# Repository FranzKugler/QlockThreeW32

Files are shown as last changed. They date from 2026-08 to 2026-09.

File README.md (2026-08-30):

# QlockThreeW32

ESP32 firmware for a **word clock** — a grid of letters, backlit so that the
current time reads as a sentence. The display changes every five minutes; four
corner LEDs fill in the minutes in between.

```
ES IST FÜNF NACH ZWEI          IT IS FIVE PAST TWO
```

Ten languages and dialects, a configuration web interface served by the clock
itself, and firmware updates through the browser. No cloud, no app, no account
— everything the clock needs it carries, and it works on a network with no
internet access at all.

---

## What it does

- **Ten languages**: German (standard, Swabian, Bavarian, Saxon), Swiss German,
  English, French, Italian, Dutch, Spanish. Each has its own irregular grammar
  — French and Italian agree the hour, the German dialects differ on
  *viertel* / *dreiviertel*.
- **Configuration in the browser**, served from the clock. The interface
  switches its own language along with the clock's.
- **Colour** as hue, saturation and brightness, beside a live preview of the
  real face — the lit letters are read back out of the clock's own frame
  buffer, not guessed at in the browser.
- **Automatic brightness** from an ambient light sensor, on a curve the clock
  learns from the way you use the slider — and, on a calibrated clock,
  **colour-aware**: the same setting emits far less light in deep blue than
  in green, and the automatic knows it. There is no "remember this" button.
- **Time from NTP**, with a region/place picker over both daylight-saving
  changeover rules, which stay editable by hand underneath.
- **Firmware and interface updates** from the browser, or automatically from a
  release channel.
- **Expert mode** — a password in front of the update, debug and storage tabs.
- A few debug displays: seconds counter, LED test pattern.

## Hardware

| | |
|---|---|
| Controller | Seeed XIAO ESP32-S3 **Plus** (16 MB flash) |
| LEDs | 114 × WS2812B on one strip, data on GPIO 4 |
| Layout | 11 × 10 letters = 110, plus 4 corner LEDs |
| Light sensor | ams **TSL2591** (0x29) or Vishay **VEML7700** (0x10) on I²C, SDA/SCL default to GPIO 5/6 — optional |

The strip starts at the **bottom right** letter, meanders left, then up one row
and back to the right, and ends at the **top right**. The four corner LEDs
follow it, in the order bottom right, top right, top left, bottom left.

```
index 0    bottom right   (the R of the German panel)
index 109  top right      (the F)
110 … 113  the corners
```

> `LedDriverWS2812FastLED::physicalFor(row, col)` is the only place that
> computes this, and the `/lab` interface can check any claim about it against
> the strip in seconds. Which frame buffer *row* is which corner is a separate
> question and lives at `Renderer::setCorners` — the path there goes through
> two remappings that partly cancel, and it was settled by watching a clock
> rather than by reading code.

**Either light sensor works, and the choice is made at run time** — the firmware
tries each in turn at boot and keeps the first that answers, so one build
serves every clock and a chip swapped on the bench needs no rebuild. The
TSL2591 is asked first: the two do not share an address, so a clock carrying
both answers twice, and the more sensitive one is the one to keep. With no
sensor fitted, the automatic hides itself rather than offering a switch that
does nothing.

The board and the case are in [`hardware/`](hardware/) — a KiCad project and an
OpenSCAD model. The letter mask is **not** drawn by hand: `scripts/panels.py`
reads the ten rows out of the firmware's own language files and writes
`panels.scad`, so the sheet that gets milled and the words the clock lights
cannot drift apart.

Earlier revisions supported other boards and LED drivers; the project has since
been consolidated onto this single target.

## Building

Two halves are built separately: the firmware, and the web interface that is
flashed into the clock's filesystem.

```sh
# web interface -> data/
npm install
npm run build

# firmware
pio run                  # build
pio run -t upload        # flash the firmware
pio run -t uploadfs      # flash data/ as the filesystem image
```

Both have to be flashed once over USB. After that, updates can go through the
browser.

> The board definition in PlatformIO describes the 8 MB XIAO ESP32-S3. This is
> the Plus with 16 MB, so [`platformio.ini`](platformio.ini) overrides the
> flash size and points at [`partitions.csv`](partitions.csv): two 6.5 MB OTA
> slots and a 3.5 MB filesystem.

### Credentials

Copy [`src/Secrets.example.h`](src/Secrets.example.h) to `src/Secrets.h` and
put in your own values — it is not in version control. The build works without
it, it just leaves network flashing via espota unprotected and says so with a
compiler warning.

## First start

With no WiFi configured the clock opens an access point called
**QlockThreeW32**. Connect to it and a captive portal asks for the network.
Afterwards the clock is reachable at **http://qlockthreew32.local** or by its
address in the network.

The clock can be renamed in the WLAN tab, which changes all six places the name
appears — mDNS, the DHCP name the router lists, the setup access point, the
espota target, the RemoteDebug host and the heading of the interface. It
restarts to do it, and says so.

Four tabs are open to anyone on the network:

| Tab | |
|---|---|
| Display | operating mode, language, corner LED direction and colour |
| Colour | hue, saturation, brightness, the automatic, and a preview of the face |
| Time zone | NTP server, a region/place picker, and both changeover rules |
| WLAN | status, scan, switching networks, renaming the clock |

Switching networks is deliberately careful: the clock tries the new
credentials, and if they do not come up within twenty seconds it returns to the
previous network by itself, so a typo cannot lock you out.

## Expert mode

Three more tabs — **Update**, **Debug** and **Storage** — are behind a
password, because flashing the clock, reading its log and rummaging through its
filesystem are not things every guest on the network should be able to do.

**The way in is the address bar: `http://<clock>/#expert`.** There is no chip
in the tab row, on purpose; a visible one would only invite guessing.

- A clock that has never been given a password takes the first one offered, and
  keeps it. Until then it is exactly as open as every clock was before this
  existed.
- It is a **mode, not a login**: one flag in NVS, so the password crosses the
  wire once instead of on every poll of the log. While unlocked, nothing is
  protected — hence the visible "lock again" button.
- **The way back from a forgotten password is the plug.** The enrolment can be
  cleared within five minutes of a *power-on* reset, which a restart from the
  clock's own update tab does not count as. Anyone who can pull the plug can
  read the flash over USB anyway, so this admits what is already true rather
  than pretending otherwise.
- Five wrong answers stop the endpoint for five minutes.

What it is worth: it keeps out someone who joins the network and goes looking.
It does not keep out someone watching the traffic — there is no TLS on the
clock — and it does not keep out anyone holding it.

Once unlocked:

| Tab | |
|---|---|
| Update | installed versions, browser upload, release channel and automatic installs |
| Debug | uptime, reset reason, heap, and the clock's last 200 log lines |
| Storage | a file explorer over LittleFS, and over NVS drawn as a tree |

### The lab interface

`/lab/*` hands a script direct control of every pixel and of the light sensor —
raw colours, no gamma, no smoothing, and a whole measurement series in one
request. [`scripts/lab.py`](scripts/lab.py) is the client:

```sh
python scripts/lab.py <address> find   # which cell is the light sensor in
python scripts/lab.py <address> ir     # does the infrared channel see the room
python scripts/lab.py <address> map    # coupling from every cell to the sensor
```

It is there because a word clock whose sensor can see its own face cannot
regulate on it, and how badly is a question of geometry that differs from clock
to clock. On the first clock it ran on it found the sensor in four minutes,
behind an unused filler letter three rows from the bottom.

Behind expert mode, and it never touches a setting: the mode it uses cannot be
stored, cannot be picked in the display tab, and ends with a restart.

Two more screens have no chip either. `#luminance` draws what the automatic
brightness has learned — deliberately *outside* expert mode, since there is no
secret in a brightness curve. `#expert` is the one above.

## Automatic brightness

Switch it on in the colour tab and the display follows the room. The curve is a
straight line in **log light**, because perception is roughly logarithmic and
the range to cover spans decades:

```
brightness = slope × log10(lux) + offset      held between 20 % and 100 %
```

**There is no "remember this" button, and that is the design.** Moving the
slider is the only signal anyone ever gives about whether the automatic got it
right, so the nudge *is* the calibration:

1. Move the brightness slider while the automatic is on. The automatic steps
   aside at once — nobody wants the clock arguing back mid-drag.
2. Ten seconds after the last move, the clock keeps the pair *(light now,
   brightness asked for)* and fits a new line through everything it has kept.

The switch keeps saying "automatic" throughout, because it still is: it is
being taught, not turned off. The timer is in the firmware, so closing the tab
mid-adjustment does not lose the point.

Ten points are kept, in NVS. A new one **replaces a near neighbour** rather
than joining the queue, or ten corrections made in one evening would push the
one daylight point out and collapse the line onto a single lighting condition.
If the points sit too close together to say anything about steepness, only the
level is re-fitted and the slope stands. A slope that would make a darker room
brighter is refused outright.

The reset button in the colour tab throws it all away and restores a cautious
default line.

### Colour-aware, on a calibrated clock

That single line is the fallback. A clock shipped with a measured optical
profile knows that a percentage is not an amount of light — the same setting
emits far less in deep blue than in the green this clock normally shows — and
regulates on a small model of the diffuser and LEDs instead: one line shared
by every colour, plus how each hue departs from it. Nudging the slider still
teaches it, now per colour, and a taught correction only overrides the factory
measurement where it actually disagrees with it — elsewhere the factory
number keeps speaking for itself, which is why a handful of evening
corrections in one colour do not retune the whole curve.

`#luminance` — reachable without unlocking expert mode, since there is no
secret in a brightness curve — draws the model as an interactive 3D surface:
hue running round, ambient light out from the centre (logarithmically,
brighter towards the middle), brightness as the height, with every taught
correction marked on it. A collapsible "fit parameters" section beside it has
the numbers themselves, for anyone curious.

## The two stores

The clock keeps things in two places, and the difference decides what survives
an update:

- **LittleFS**, 3.5 MB — the web interface, the timezone list, the icons. A
  filesystem update **overwrites it whole**.
- **NVS** — the settings, the expert password, the brightness curve. An update
  leaves it **untouched**, which is exactly why they live there.

The **Storage** tab shows both. NVS is not a filesystem and is drawn as one
anyway: namespaces as folders, keys as files, `.json` or `.bin` depending on
what the value turns out to be. Files can be downloaded, uploaded and edited in
place, JSON laid out on the way in and written back compact. Right-click, or
press and hold on a touch screen, for the menu.

Two things it will not do. The expert password hash is listed but never handed
out — it is the one secret whose leak would outlive the unlock that leaked it.
And deleting is not recursive, because a file explorer that empties a tree on
one click is how the web interface gets deleted by someone who meant to tidy
up.

> Clearing NVS resets the clock to defaults. Reflashing the filesystem no
> longer does.

## Flashing a blank chip

**[franzkugler.github.io/QlockThreeW32](https://franzkugler.github.io/QlockThreeW32/)**
flashes a factory-fresh Seeed XIAO ESP32-S3 Plus straight from Chrome, Edge or
Opera — no PlatformIO, no Python, nothing to install. It writes the whole
chip (bootloader, partition table, firmware and the configuration interface)
from whatever the latest stable release is, using
[ESP Web Tools](https://esphome.github.io/esp-web-tools/) over the Web Serial
API. Once a clock is running this firmware, updates go through its own
**Update** tab instead — see the next section.

The page is [`docs/`](docs/) in this repository, published as a GitHub Pages
site by [the release workflow](.github/workflows/release.yml) on every stable
release; see [`CLAUDE.md`](CLAUDE.md) for why it cannot simply point at the
release's own download URLs.

## Updating over the air

There are two images, and they are independent: `firmware.bin` (the program)
and `littlefs.bin` (the web interface). Changing the interface and only
flashing the firmware leaves the old interface in place.

Ready-built images come from
[the releases page](https://github.com/FranzKugler/QlockThreeW32/releases), in
two channels:

- **stable** — tagged versions, built from a `v*` tag.
- **edge** — a rolling build of the latest commit on `main`, replaced on every
  push. Untested by definition.

The clock can poll its channel by itself and install what it finds. Automatic
installs are off by default and only ever run between 02:00 and 05:00 local, so
the face never goes dark in the evening.

Locally the images are produced by `pio run` and `pio run -t buildfs` in
`.pio/build/seeed_xiao_esp32s3/`.

Upload either image in the **Update** tab — the clock recognises which is which
from the image itself (ESP32 program images start with the magic byte `0xE9`)
and picks the right partition.

The checksum is verified before the boot partition is switched, so an
interrupted upload does no harm: the clock simply keeps running the version it
has. There is no automatic rollback for an image that flashes correctly but
then crashes — that case needs a USB cable.

**The update endpoints are behind expert mode**, along with the log and the
storage tab. They were open by design while none of them existed as a web page.

## Layout of the repository

```
src/            firmware (PlatformIO / Arduino-ESP32)
  Renderer.*      hour/minute -> which words light up, no hardware involved
  languages/      one file per language: its letters, its words, its grammar
  LedDriver*      WS2812B output, colour and brightness
  LightSensor.*   TSL2591 / VEML7700 behind one interface, sampled on core 0
  Luminance.*     the brightness curve, and how it is learned
  FactoryProfile.*    the colour-aware model, as pure arithmetic
  FactoryLuminance.*  loads and validates the measured profile from LittleFS
  ResidualStore.*     what an owner has taught it, refit online against the profile
  Settings.*      persistence in NVS
  WebRoutes.*     the HTTP handlers; OtaUpdate, FileRoutes, NvsRoutes beside it
web/            configuration interface (Svelte 5 + Vite), built into data/
hardware/       KiCad project, and the OpenSCAD case and letter mask
scripts/        generators: the letter mask, the timezone list, the app icons
server.js       mock of the clock's REST API, for developing the UI without hardware
```

Everything in `scripts/` writes files that are **committed**, so neither a
build nor a 3D print needs Python. Edit the generator, never its output.

For UI work, run the mock and the dev server side by side — the interface then
behaves as it does on the device, on a desktop browser:

```sh
npm run mock     # REST API on :8080
npm run dev      # Vite with hot reload on :5173
```

[`CLAUDE.md`](CLAUDE.md) goes into the architecture in more detail.

## Origins

This is a long-running hobby project, and not the beginning of the story. It
descends from **Qlockthree** by *Christian Aschoff* — firmware for a
self-built QLOCKTWO-style clock, written for the Arduino/ATmega328 from
November 2011 onwards and maintained through version 3.4.9. Much of the
rendering code here is still his, as the file headers record.

- Project and downloads: <http://www.christians-bastel-laden.de/DOWNLOADS/index.html>
- Shop and build instructions: <http://www.christians-bastel-laden.de/>

The upstream firmware is not on GitHub itself; it is published as ZIP archives
on that page. Several people have mirrored and continued it, among them
[bracci/Qlockthree](https://github.com/bracci/Qlockthree),
[schwabe/qlockthree](https://github.com/schwabe/qlockthree) and
[cactus-online/Qlockthree](https://github.com/cactus-online/Qlockthree).
[bracci/QlockWiFive](https://github.com/bracci/QlockWiFive) and
[ch570512/Qlockwork](https://github.com/ch570512/Qlockwork) are separate ESP
firmwares for the same hardware idea.

Beyond that, the Swiss German variant goes back to *Thomas Schuler* and the
Dutch one to *Rudolf Klimesch*.

This repository takes that lineage to an ESP32-S3, and adds the web interface,
the WiFi handling and the over-the-air updates.

## License

**CC BY-NC-SA 3.0** — Attribution, NonCommercial, ShareAlike. See
[`LICENSE`](LICENSE).

This is inherited, not chosen: Christian Aschoff puts the original firmware
under CC BY-NC-SA 3.0, and the ShareAlike term carries over to anything built
on it. In short — keep the attributions, do not use it commercially, and pass
derivatives on under the same terms.

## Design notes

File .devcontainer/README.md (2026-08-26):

# QlockThreeW32 development container

The container pins the development tools used by this repository:

- Debian 12 / Node.js 22
- Python 3.11
- PlatformIO Core 6.1.19
- Claude Code 2.1.246
- uv 0.12.5

The repository is bind-mounted at `/workspace`. PlatformIO, npm, and Claude
state use separate named volumes, so package downloads and authentication
survive container recreation. The container has no Docker socket, no devices,
no added capabilities, is not privileged, and runs as UID/GID 1001.

## Commands

From the repository root:

```bash
./scripts/dev-container.sh up       # build and start
./scripts/dev-container.sh shell    # interactive shell
./scripts/dev-container.sh build    # npm + firmware + LittleFS
./scripts/dev-container.sh claude   # interactive Claude Code
./scripts/dev-container.sh down     # stop; keep caches
```

Claude authentication is intentionally separate from the host credential
store. Run `./scripts/dev-container.sh claude`, complete `claude auth login`
once, and the login is retained in the `claude-state` volume.

The Vite UI is bound to host loopback port 5173. The mock API remains on port
8080 inside the container but is published as `127.0.0.1:18080`, because port
8080 on this server is already used by another service.

## VS Code

Open the repository and choose **Dev Containers: Reopen in Container**. The
configuration is in `devcontainer.json` and installs the PlatformIO and Svelte
extensions.

## ESP32 USB access

No USB device is exposed by default. Builds and filesystem image creation work
without it. Flashing will be added as a deliberate, device-specific Compose
override after the ESP32 is physically attached and its stable `/dev/serial/by-id/`
path and group ownership are known. Do not use `privileged: true`.

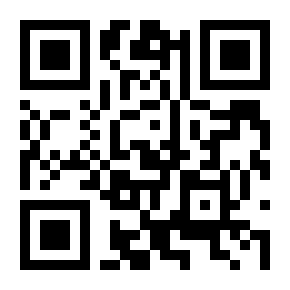
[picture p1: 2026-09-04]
docs/qr-clock.png

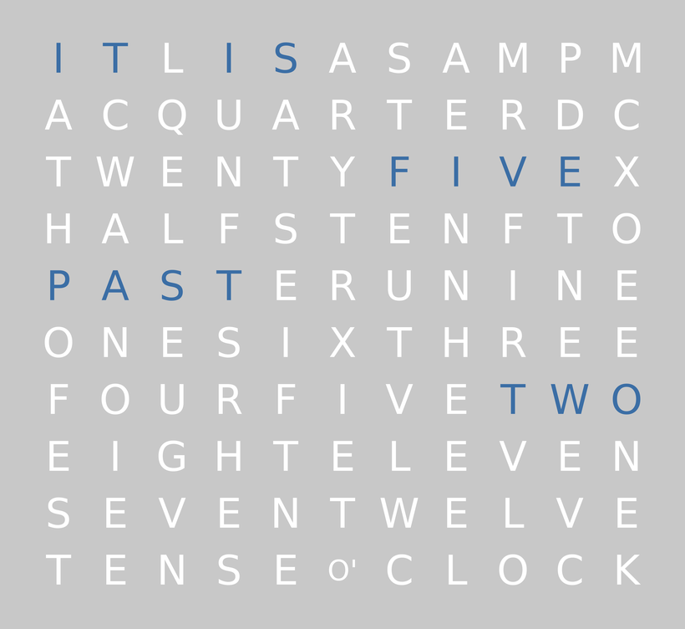
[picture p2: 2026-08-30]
docs/panel-preview.png

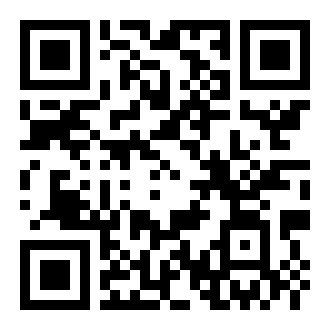
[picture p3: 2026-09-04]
docs/qr-ap.png

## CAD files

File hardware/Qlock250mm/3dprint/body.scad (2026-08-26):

include <BOSL2/std.scad>
include <BOSL2/screws.scad>
include <panels.scad>       // generated by scripts/panels.py

size = 250;
pcb_size = 240;
wall = 14;                  
mask_thickness = 3;         // thickness of mask (white PETG)
body_thickness = 24;        // makes a total thickness of 30mm, 3mm diffusor window, 3mm lid and 24mm body.
lid_thickness = 3;          // 3mm to have the same look and feel for front and back
ldx = 1000 / 60;            // LED distance in x
ldy = ldx * 11 / 10;        // calculated for a square panel
lettersize = ldy*4/7;       // calculated letter size (height) - relative to height of cell
grid_thickness = 2;
tol = 0.2;                  // Tolerance

//font="Garamond:style=Bold";
//font="Century Gothic:style=Bold";
font ="";

// The panel to cut, by the code the firmware uses. The letters used to be
// written out here as well, which meant two copies and only one of them
// checked - the clock verifies its own at every boot. See panels.scad for
// what is on offer.
display = panel("de-BA");  //de-BA


module body(){
    difference() {
        union() {
            //masking plate
            difference() {
                cuboid([size,size,mask_thickness], anchor=BOTTOM); 
                //letters
                for(x=[0:10]) for(y=[0:9]) {
                    // we're adjusted to baseline, so calculate offset that the baseline is in the middle of the cell
                    dy = textmetrics("A", lettersize, font=font).size[1] / 2;
                    // now place the correct letter at its place
                    translate([(5-x)*ldx, (4.5-y)*ldy-dy ,-1])
                        linear_extrude(mask_thickness+2)mirror([1,0,0])text(display[y][x], lettersize, font, halign="center", valign="baseline", $fn=64);
                }
                
                //corners
                for(x=[0:1])for(y=[0:1])
                    translate([6*ldx*(2*x-1),5.5*ldy*(2*y-1),-1])cylinder(d=4, h=mask_thickness+2, $fn=32);
                
                // light sensor  
                translate([0,5.5*ldy,-1])cylinder(d=5, h=5);
            }
           
            //frame
            difference(){
                cuboid([size,size,body_thickness], anchor=BOTTOM);
                translate([0,0,-1])cuboid([size-2*wall,size-2*wall,body_thickness+2], anchor=BOTTOM);
                translate([0,0,15])cuboid([pcb_size+1,pcb_size+1,30], anchor=BOTTOM);     // PCB sitting at height 15mm, 3mm mask thickness, 2mm LED height = distance of 10mm.
            }
        }
        // make cutouts for the grid
        translate([0,0,20+1-tol])rotate([180,0,180])grid(grid_thickness+2*tol, 20);
        
        // holes for M3 inserts
        translate([ 120-4, 120-4, 3])cylinder(d=4, h=20, $fn=32);
        translate([ 120-4,-120+4, 3])cylinder(d=4, h=20, $fn=32);
        translate([-120+4, 120-4, 3])cylinder(d=4, h=20, $fn=32);
        translate([-120+4,-120+4, 3])cylinder(d=4, h=20, $fn=32);

        // cutout for USB cable
        translate([0,-size/2+24,17-1.6])cuboid([16,30,30], rounding=2, edges="Y", anchor=BACK+BOTTOM, $fn=64);
        translate([0,(-pcb_size-1)/2,mask_thickness])cuboid([16,30,30], rounding=2,  anchor=FRONT+BOTTOM, $fn=64);
    }
}

module grid(gt,h){
    l=size-2*wall;
    f=2.6;
    difference() {
        union() {
            // grid-fins running up-down
            for(x=[0:13])translate([(6.5-x)*ldx,0,0]){
                if (x==0 || x==13) {
                    cuboid([gt, 12*ldy+grid_thickness, h], anchor=BOTTOM);
                } else {
                    cuboid([gt, l+6, h], anchor=BOTTOM);
            }}
            // grid-fins running left-right
            for(y=[0:12])translate([0,(6-y)*ldy,0]) {
                if (y==0 || y==12) {
                    cuboid([13*ldx+grid_thickness, gt, h], anchor=BOTTOM); 
                } else {
                    cuboid([l+6,gt, h], anchor=BOTTOM);
            }}
            // base plate sitting directly on PCB
            cuboid([13*ldx, 12*ldy, f], anchor=BOTTOM);
            // filled cells to hold the M3 inserts
            for(x=[-6*ldx, 6*ldx])for(y=[-3.5*ldy, 3.5*ldy]){
                translate([x,y,0])cuboid([ldx, ldy, 7], anchor=BOTTOM);
            }    
        }
        // cutout for letter LEDs with capacitors
        for(x=[0:10]) for(y=[0:9]) {
            translate([(5-x)*ldx,   (4.5-y)*ldy ,-1]) cuboid([6.5, 6.5, f+2], anchor=BOTTOM);
            translate([(5-x)*ldx+5, (4.5-y)*ldy ,-1]) cuboid([1.6, 3, 2.6], anchor=BOTTOM);
        }
        // cutout for corner LEDs with capacitors
        for(x=[0:1])for(y=[0:1]) {
            translate([6*ldx*(2*x-1),   5.5*ldy*(2*y-1),-1]) cuboid([6.5, 6.5, f+2], anchor=BOTTOM);
            translate([6*ldx*(2*x-1)+5, 5.5*ldy*(2*y-1),-1]) cuboid([1.6, 3, 2.6], anchor=BOTTOM);
        }
        // cutout for light sensor
        translate([0,5.5*ldy,-1]) cuboid([ldx-grid_thickness, ldy-grid_thickness, f+2], anchor=BOTTOM);

        // cutout for line driver
        translate([4*ldx,-5.5*ldy,-1]) cuboid([ldx-grid_thickness, ldy-grid_thickness, f+2], anchor=BOTTOM);
        
        // cutout for capacitor
        translate([5*ldx,-5.5*ldy,-1]) cuboid([ldx-grid_thickness, ldy-grid_thickness, f+2], anchor=BOTTOM);

        // cutout for USB connector
        translate([0,-6.5*ldy,-1]) cuboid([3*ldx-grid_thickness, 3*ldy-grid_thickness,40]);
        
        // holes for M3 inserts
        for(x=[-6*ldx-3, 6*ldx+3])for(y=[-3.5*ldy, 3.5*ldy]) {
            translate([x,y,-1])cylinder(d=4, h=6, $fn=32);
            echo(160+x,160+y);
        }
    }
}

module lid() {
    difference(){
        union() {
            cuboid([size, size, lid_thickness], anchor=BOTTOM);
            cuboid([pcb_size+1-tol, pcb_size+1-tol, 10], rounding=4, edges="Z", anchor=BOTTOM, $fn=32);

        }
        // mounting screw holes
        for (x=[-120+4, 120-4])for(y=[-120+4, 120-4])translate([x,y,0])rotate([180,0,0])screw_hole("M3", length=10, head="flat", anchor=TOP, $fn=32);

        // make room for the screws holding the grid 
        for(x=[-6*ldx-3, 6*ldx+3])for(y=[-3.5*ldy, 3.5*ldy])translate([x,y,3])cylinder(d=8, h=20, $fn=32);

        // make room for the esp32
        translate([0,-size/2+55,4])cuboid([20,60,20], rounding=2, anchor=BACK+BOTTOM, $fn=64);
        // and the usb cable
        translate([0,-size/2+24,-5])cuboid([16,30,20], rounding=2, anchor=BACK+BOTTOM, $fn=64);
    }

}

module assembly()
{
    // translucent Plate
    color("lightblue", alpha=0.3)cuboid([size,size,3], anchor=TOP);
    // white main body with letters
    color("white")body();
    // black separation grid
    color("black")translate([0,0,1+14])rotate([180,0,180])grid(grid_thickness,2+10+2);
    // PCB with LEDs
    color("lime")translate([0,0,16.6])rotate([180,0,180])import("./stl/board.stl");
    // lid
    color("lightblue")translate([0,0,30-3])rotate([180,0,180])lid();
}

body();

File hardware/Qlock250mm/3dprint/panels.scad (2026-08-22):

/*
 * The clock's letter panels, generated by scripts/panels.py out of the
 * language files the firmware renders with. Do not edit by hand: a change
 * here would be a panel the clock does not have.
 *
 * Eleven columns by ten rows, row 0 at the top and column 0 on the left,
 * which is how the firmware indexes them too.
 */

// Deutsch, Schwäbisch, Bayrisch, Sächsisch
panel_DE = [
    ["E", "S", "K", "I", "S", "T", "A", "F", "Ü", "N", "F"],
    ["Z", "E", "H", "N", "Z", "W", "A", "N", "Z", "I", "G"],
    ["D", "R", "E", "I", "V", "I", "E", "R", "T", "E", "L"],
    ["V", "O", "R", "F", "U", "N", "K", "N", "A", "C", "H"],
    ["H", "A", "L", "B", "A", "E", "L", "F", "Ü", "N", "F"],
    ["E", "I", "N", "S", "X", "A", "M", "Z", "W", "E", "I"],
    ["D", "R", "E", "I", "A", "U", "J", "V", "I", "E", "R"],
    ["S", "E", "C", "H", "S", "N", "L", "A", "C", "H", "T"],
    ["S", "I", "E", "B", "E", "N", "Z", "W", "Ö", "L", "F"],
    ["Z", "E", "H", "N", "E", "U", "N", "K", "U", "H", "R"]
];

// Schwiizerdütsch
panel_CH = [
    ["E", "S", "K", "I", "S", "C", "H", "A", "F", "Ü", "F"],
    ["V", "I", "E", "R", "T", "U", "B", "F", "Z", "Ä", "Ä"],
    ["Z", "W", "Ä", "N", "Z", "G", "S", "I", "V", "O", "R"],
    ["A", "B", "O", "H", "A", "U", "B", "I", "E", "G", "E"],
    ["E", "I", "S", "Z", "W", "Ö", "I", "S", "D", "R", "Ü"],
    ["V", "I", "E", "R", "I", "F", "Ü", "F", "I", "Q", "T"],
    ["S", "Ä", "C", "H", "S", "I", "S", "I", "B", "N", "I"],
    ["A", "C", "H", "T", "I", "N", "Ü", "N", "I", "E", "L"],
    ["Z", "Ä", "N", "I", "E", "R", "B", "E", "U", "F", "I"],
    ["Z", "W", "Ö", "U", "F", "I", "N", "A", "U", "H", "R"]
];

// English
panel_EN = [
    ["I", "T", "L", "I", "S", "A", "S", "A", "M", "P", "M"],
    ["A", "C", "Q", "U", "A", "R", "T", "E", "R", "D", "C"],
    ["T", "W", "E", "N", "T", "Y", "F", "I", "V", "E", "X"],
    ["H", "A", "L", "F", "S", "T", "E", "N", "F", "T", "O"],
    ["P", "A", "S", "T", "E", "R", "U", "N", "I", "N", "E"],
    ["O", "N", "E", "S", "I", "X", "T", "H", "R", "E", "E"],
    ["F", "O", "U", "R", "F", "I", "V", "E", "T", "W", "O"],
    ["E", "I", "G", "H", "T", "E", "L", "E", "V", "E", "N"],
    ["S", "E", "V", "E", "N", "T", "W", "E", "L", "V", "E"],
    ["T", "E", "N", "S", "E", "O'", "C", "L", "O", "C", "K"]
];

// Français
panel_FR = [
    ["I", "L", "N", "E", "S", "T", "O", "D", "E", "U", "X"],
    ["Q", "U", "A", "T", "R", "E", "T", "R", "O", "I", "S"],
    ["N", "E", "U", "F", "U", "N", "E", "S", "E", "P", "T"],
    ["H", "U", "I", "T", "S", "I", "X", "C", "I", "N", "Q"],
    ["M", "I", "D", "I", "X", "M", "I", "N", "U", "I", "T"],
    ["O", "N", "Z", "E", "R", "H", "E", "U", "R", "E", "S"],
    ["M", "O", "I", "N", "S", "O", "L", "E", "D", "I", "X"],
    ["E", "T", "R", "Q", "U", "A", "R", "T", "P", "M", "D"],
    ["V", "I", "N", "G", "T", "-", "C", "I", "N", "Q", "U"],
    ["E", "T", "S", "D", "E", "M", "I", "E", "P", "A", "M"]
];

// Italiano
panel_IT = [
    ["S", "O", "N", "O", "R", "L", "E", "B", "O", "R", "E"],
    ["È", "R", "Ľ", "U", "N", "A", "S", "D", "U", "E", "Z"],
    ["T", "R", "E", "O", "T", "T", "O", "N", "O", "V", "E"],
    ["D", "I", "E", "C", "I", "U", "N", "D", "I", "C", "I"],
    ["D", "O", "D", "I", "C", "I", "S", "E", "T", "T", "E"],
    ["Q", "U", "A", "T", "T", "R", "O", "C", "S", "E", "I"],
    ["C", "I", "N", "Q", "U", "E", "S", "M", "E", "N", "O"],
    ["E", "C", "U", "N", "O", "Q", "U", "A", "R", "T", "O"],
    ["V", "E", "N", "T", "I", "C", "I", "N", "Q", "U", "E"],
    ["D", "I", "E", "C", "I", "E", "M", "E", "Z", "Z", "A"]
];

// Nederlands
panel_NL = [
    ["H", "E", "T", "K", "I", "S", "A", "V", "I", "J", "F"],
    ["T", "I", "E", "N", "A", "T", "Z", "V", "O", "O", "R"],
    ["O", "V", "E", "R", "M", "E", "K", "W", "A", "R", "T"],
    ["H", "A", "L", "F", "S", "P", "M", "O", "V", "E", "R"],
    ["V", "O", "O", "R", "T", "H", "G", "É", "É", "N", "S"],
    ["T", "W", "E", "E", "A", "M", "C", "D", "R", "I", "E"],
    ["V", "I", "E", "R", "V", "I", "J", "F", "Z", "E", "S"],
    ["Z", "E", "V", "E", "N", "O", "N", "E", "G", "E", "N"],
    ["A", "C", "H", "T", "T", "I", "E", "N", "E", "L", "F"],
    ["T", "W", "A", "A", "L", "F", "P", "M", "U", "U", "R"]
];

// Español
panel_ES = [
    ["E", "S", "O", "N", "E", "L", "A", "S", "U", "N", "A"],
    ["D", "O", "S", "I", "T", "R", "E", "S", "O", "A", "M"],
    ["C", "U", "A", "T", "R", "O", "C", "I", "N", "C", "O"],
    ["S", "E", "I", "S", "A", "S", "I", "E", "T", "E", "N"],
    ["O", "C", "H", "O", "N", "U", "E", "V", "E", "P", "M"],
    ["L", "A", "D", "I", "E", "Z", "S", "O", "N", "C", "E"],
    ["D", "O", "C", "E", "L", "Y", "M", "E", "N", "O", "S"],
    ["O", "V", "E", "I", "N", "T", "E", "D", "I", "E", "Z"],
    ["V", "E", "I", "N", "T", "I", "C", "I", "N", "C", "O"],
    ["M", "E", "D", "I", "A", "C", "U", "A", "R", "T", "O"]
];

// Every language the firmware knows, in the order of its LANGUAGE_*
// numbers - which are stored in NVS and must keep their values.
panels = [
    ["de-DE", panel_DE],   // Deutsch
    ["de-SW", panel_DE],   // Schwäbisch
    ["de-BA", panel_DE],   // Bayrisch
    ["de-SA", panel_DE],   // Sächsisch
    ["de-CH", panel_CH],   // Schwiizerdütsch
    ["en",    panel_EN],   // English
    ["fr",    panel_FR],   // Français
    ["it",    panel_IT],   // Italiano
    ["nl",    panel_NL],   // Nederlands
    ["es",    panel_ES]   // Español
];

// The letters of one language, e.g. panel("de-DE"). A code that is not
// in the list gives undef, which OpenSCAD complains about loudly enough.
function panel(code) = [for (p = panels) if (p[0] == code) p[1]][0];

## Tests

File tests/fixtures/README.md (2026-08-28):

# Test fixtures

Copies, byte for byte, of measurement records that live outside this repository.
They are committed here so the tests depend on a **fixed** artefact rather than on
a mutable working path, and so a run on another machine measures the same thing.

Nothing here is regenerated by a build. If a source file changes, copy it in
again deliberately and expect the profile checksum test to change with it — that
is what the checksum is for.

| File | Copied from | sha256 |
|---|---|---|
| `2026-08-26-manual-colour-brightness-points.json` | `/workspace/.hermes/measurements/2026-08-26-manual-colour-brightness-points.json`, as at 2026-08-26 | `5c9211389f8c8a661f29cadef360ab6bc223e2546b150e154aed43c581866a7e` |
| `2026-08-27-manual-colour-brightness-points-with-hue240-repeat.json` | the same mutable path, as at 2026-08-27, after the targeted hue-240 repeat was added | `a9679dfda6aebe02880f00e66d443efc619ee1a2edc0b6f5d4a10c63da7dcf62` |
| `2026-08-26-current-diffuser-before-mask-coupling.json` | `/workspace/coupling.json` (per-clock, gitignored at the repository root; JSON content preserved, line endings normalized to LF) | `b6f1e2c28869e69155c6033f9811e4878d1be62dd74781bb4e46b96ba91ed96d` |

**Both measurement records are kept.** The 2026-08-26 one pins what the model
did before the repeat existed, so a change in the numbers is visible as a
change rather than absorbed into a new baseline. The 2026-08-27 one is the
same record with eight points added; nothing in it was edited or removed.

## The measurement record

Manual visual settings supplied by Franz, taken on the clock whose optical stack
is `current-diffuser-before-mask`. Every point is a slider percentage somebody
chose by eye at a stated ambient level, for a stated hue and saturation. It is
**not** read from clock NVS: the near-light replacement ignores colour, so the
points were preserved externally.

Six drift-controlled rounds are usable, each `W-0-180-W-60-240-W-120-300-W` with
white anchors interleaved so the round can be corrected for the observer drifting
over the ten minutes it takes:

| lux | round id | white anchors | note |
|---:|---|---|---|
| 0.02 | `dark-room-0.02-lux-drift-controlled` | 30/30/30/30 | |
| 0.07 | `dark-0.07-lux-drift-controlled` | 35/35/38/35 | |
| 0.15 | *(no `roundId`; recovered by exact `logLux`)* | 40/45 | anchors at the ends only |
| 0.5 | `mid-0.5-lux-drift-controlled` | 40/40/40/40 | |
| 1.9 | `mid-1.9-lux-drift-controlled` | 50/50/50/50 | |
| 10 | `bright-10-lux-drift-controlled-ceiling-limited` | 90/90/90/90 | four hues at the 100 % ceiling |

The eight points around 2.0–2.4 lx are **not** a round: they were taken without
interleaved white anchors, at eight different ambient levels, and one of them is
at `sat=80` on a hue that is not a knot. They are superseded by the
drift-controlled 1.9 lx round and the profile records them as excluded.

## The targeted hue-240 repeat (2026-08-27 record only)

Eight further points declared as a family, `hue240-targeted-repeat-2026-08-27`,
`kind: "targeted-repeat"`, hue 240, levels 0.02/0.15/0.5/1.9. Each level is a
two-point sitting `W-H240` under its own round id `<family>-<level>`.

They are **pairs, not rounds**: two observations say nothing about the four
hues they did not look at, and the parser refuses to treat them as a round or
to fill the missing hues in. What a pair does measure well is the same-sitting
difference between its white and its colour, which is the residual with the
observer's adaptation divided out.

| lux | round | repeat | residual difference |
|---:|---|---|---:|
| 0.02 | W 30/30/30/30, H240 50 % | W 25, H240 40 % | −0.0139 dec |
| 0.15 | W 40/45, H240 80 % | W 30, H240 55 % | **+0.1409 dec** |
| 0.5 | W 40×4, H240 70 % | W 40, H240 65 % | −0.0827 dec |
| 1.9 | W 50×4, H240 70 % | W 50, H240 70 % | 0.0000 dec |

Their **white anchors do not enter the global white baseline**, only their own
pair. At 0.15 lx the repeat's single anchor sits 0.56 decades below the round's,
and pooling it would drag the baseline every hue is measured against by 0.19
decades on the strength of one anchor from a session aimed at one colour. What
pooling would have done is reported in the profile under
`targeted.whiteBaseline.ifPooled` rather than left as an assertion.

## The coupling record

`scripts/lab.py calibrate` output for the same clock: the per-cell coupling map
and, the only part used here, the measured LED drive-response table. The drive
response is neither linear nor a gamma, and 20 % brightness comes out as a drive
of about seven — the part of the curve where assuming proportionality is worst.

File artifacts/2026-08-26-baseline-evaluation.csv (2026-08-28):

kind | source | roundId | sourceRoundId | lux | hue | sat | observed | predicted | error | censored | atLeast | honoured | bound | luxClamped | limited | foldScored | countedInAcceptance
fold | round | dark-room-0.02-lux-drift-controlled | dark-room-0.02-lux-drift-controlled | 0.02 | 0 | 100 | 30 | 41 | 11 | 0 |  |  |  | below |  | 0 | 0
fold | round | dark-room-0.02-lux-drift-controlled | dark-room-0.02-lux-drift-controlled | 0.02 | 180 | 100 | 35 | 47 | 12 | 0 |  |  |  | below |  | 0 | 0
fold | round | dark-room-0.02-lux-drift-controlled | dark-room-0.02-lux-drift-controlled | 0.02 | 60 | 100 | 40 | 45 | 5 | 0 |  |  |  | below |  | 0 | 0
fold | round | dark-room-0.02-lux-drift-controlled | dark-room-0.02-lux-drift-controlled | 0.02 | 240 | 100 | 50 | 66 | 16 | 0 |  |  |  | below |  | 0 | 0
fold | round | dark-room-0.02-lux-drift-controlled | dark-room-0.02-lux-drift-controlled | 0.02 | 120 | 100 | 35 | 43 | 8 | 0 |  |  |  | below |  | 0 | 0
fold | round | dark-room-0.02-lux-drift-controlled | dark-room-0.02-lux-drift-controlled | 0.02 | 300 | 100 | 40 | 55 | 15 | 0 |  |  |  | below |  | 0 | 0
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

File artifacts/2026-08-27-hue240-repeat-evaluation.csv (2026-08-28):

kind | source | roundId | sourceRoundId | lux | hue | sat | observed | predicted | error | censored | atLeast | honoured | bound | luxClamped | limited | foldScored | countedInAcceptance
fold | round | dark-room-0.02-lux-drift-controlled | dark-room-0.02-lux-drift-controlled | 0.02 | 0 | 100 | 30 | 41 | 11 | 0 |  |  |  | below |  | 0 | 0
fold | round | dark-room-0.02-lux-drift-controlled | dark-room-0.02-lux-drift-controlled | 0.02 | 180 | 100 | 35 | 47 | 12 | 0 |  |  |  | below |  | 0 | 0
fold | round | dark-room-0.02-lux-drift-controlled | dark-room-0.02-lux-drift-controlled | 0.02 | 60 | 100 | 40 | 45 | 5 | 0 |  |  |  | below |  | 0 | 0
fold | round | dark-room-0.02-lux-drift-controlled | dark-room-0.02-lux-drift-controlled | 0.02 | 240 | 100 | 50 | 66 | 16 | 0 |  |  |  | below |  | 0 | 0
fold | round | dark-room-0.02-lux-drift-controlled | dark-room-0.02-lux-drift-controlled | 0.02 | 120 | 100 | 35 | 43 | 8 | 0 |  |  |  | below |  | 0 | 0
fold | round | dark-room-0.02-lux-drift-controlled | dark-room-0.02-lux-drift-controlled | 0.02 | 300 | 100 | 40 | 55 | 15 | 0 |  |  |  | below |  | 0 | 0
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

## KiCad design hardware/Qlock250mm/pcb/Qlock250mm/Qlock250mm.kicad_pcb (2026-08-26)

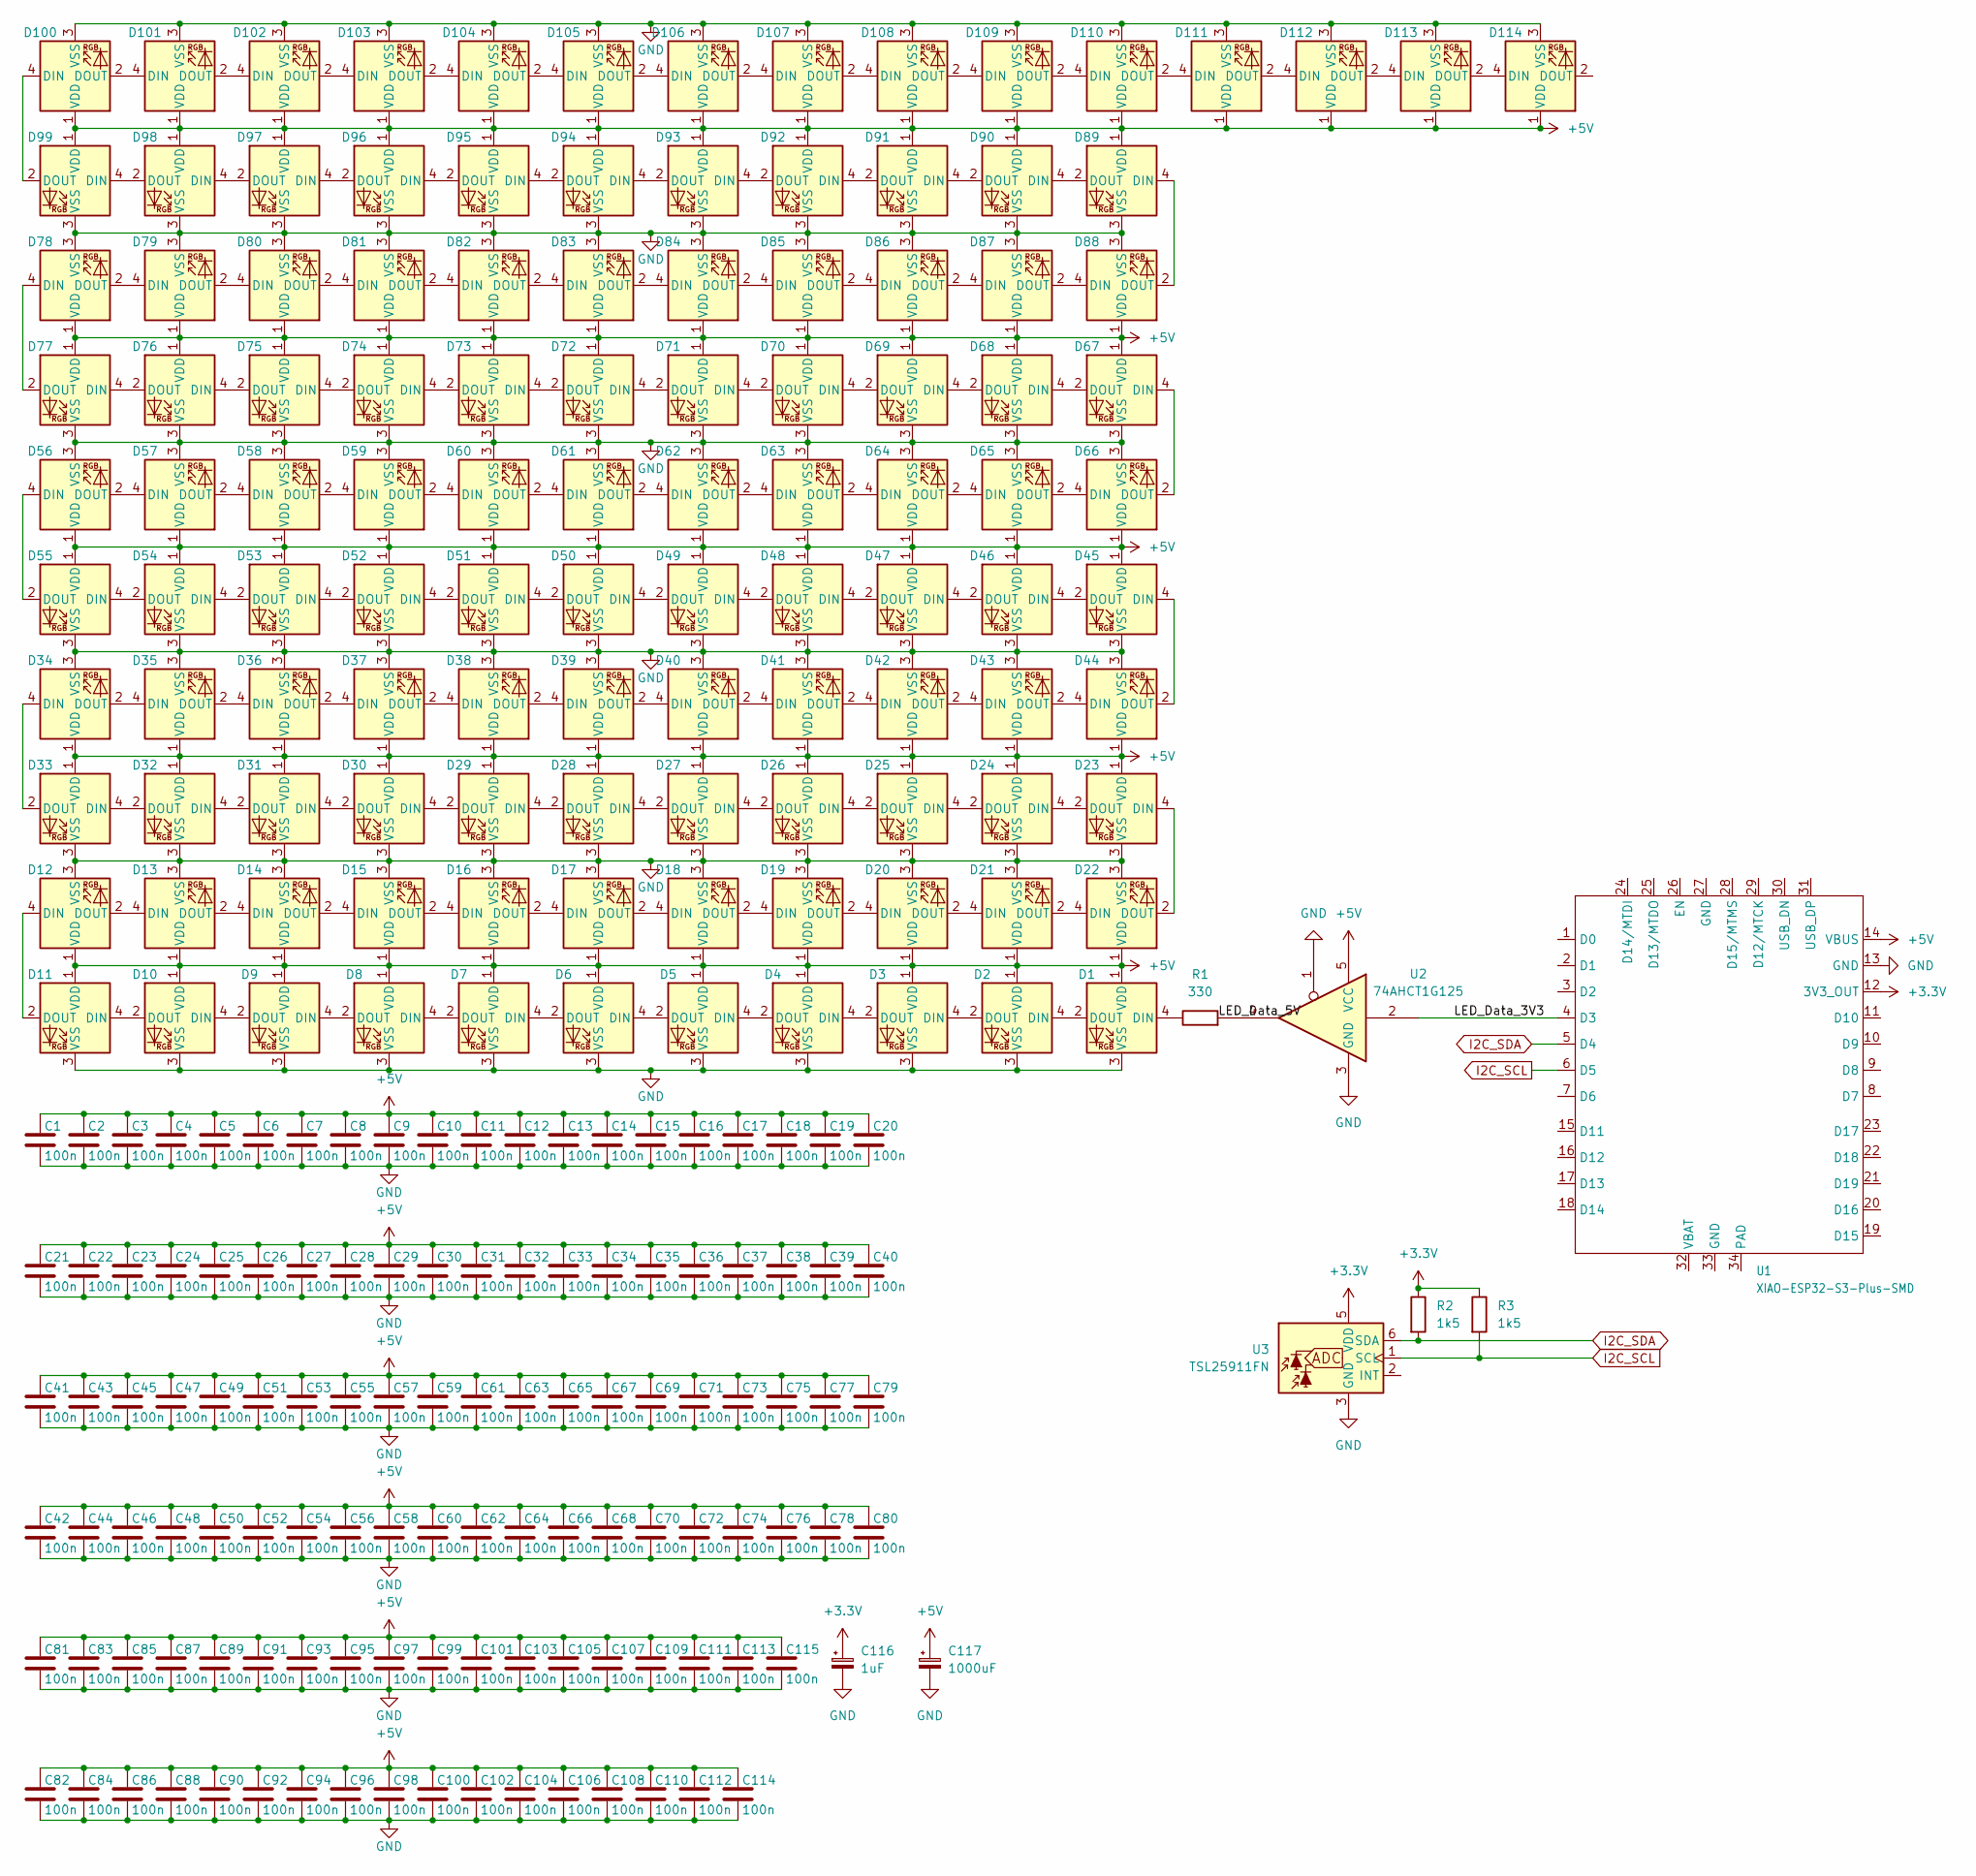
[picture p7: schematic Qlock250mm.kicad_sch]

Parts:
C1, C2, C3, C4, C5, C6, C7, C8, C9, C10, C11, C12, C13, C14, C15, C16, C17, C18, C19, C20, C21, C22, C23, C24, C25, C26, C27, C28, C29, C30, C31, C32, C33, C34, C35, C36, C37, C38, C39, C40, C41, C42, C43, C44, C45, C46, C47, C48, C49, C50, C51, C52, C53, C54, C55, C56, C57, C58, C59, C60, C61, C62, C63, C64, C65, C66, C67, C68, C69, C70, C71, C72, C73, C74, C75, C76, C77, C78, C79, C80, C81, C82, C83, C84, C85, C86, C87, C88, C89, C90, C91, C92, C93, C94, C95, C96, C97, C98, C99, C100, C101, C102, C103, C104, C105, C106, C107, C108, C109, C110, C111, C112, C113, C114, C115: 100n; C_0603_1608Metric; LCSC Part # C1588
C116: 1uF; C_0603_1608Metric; LCSC Part # C15849
C117: 1000uF; CP_Elec_10x10; LCSC Part # C249844
D1, D2, D3, D4, D5, D6, D7, D8, D9, D10, D11, D12, D13, D14, D15, D16, D17, D18, D19, D20, D21, D22, D23, D24, D25, D26, D27, D28, D29, D30, D31, D32, D33, D34, D35, D36, D37, D38, D39, D40, D41, D42, D43, D44, D45, D46, D47, D48, D49, D50, D51, D52, D53, D54, D55, D56, D57, D58, D59, D60, D61, D62, D63, D64, D65, D66, D67, D68, D69, D70, D71, D72, D73, D74, D75, D76, D77, D78, D79, D80, D81, D82, D83, D84, D85, D86, D87, D88, D89, D90, D91, D92, D93, D94, D95, D96, D97, D98, D99, D100, D101, D102, D103, D104, D105, D106, D107, D108, D109, D110, D111, D112, D113, D114: WS2812B; LED_WS2812B_PLCC4_5.0x5.0mm_P3.2mm; LCSC Part # C2843785
R1: 330; R_0402_1005Metric; LCSC Part # C25104
R2, R3: 1k5; R_0402_1005Metric; LCSC Part # C25867
U1: XIAO-ESP32-S3-Plus-SMD
U2: 74AHCT1G125; SOT-23-5; LCSC Part # C7484
U3: TSL25911FN; AMS_TSL25911FN; LCSC Part # C176812

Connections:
+3.3V: C116.1, R2.1, R3.1, U1.12 (3V3_OUT), U3.5 (VDD)
+5V: C1.1, C2.1, C3.1, C4.1, C5.1, C6.1, C7.1, C8.1, C9.1, C10.1, C11.1, C12.1, C13.1, C14.1, C15.1, C16.1, C17.1, C18.1, C19.1, C20.1, C21.1, C22.1, C23.1, C24.1, C25.1, C26.1, C27.1, C28.1, C29.1, C30.1, C31.1, C32.1, C33.1, C34.1, C35.1, C36.1, C37.1, C38.1, C39.1, C40.1, C41.1, C42.1, C43.1, C44.1, C45.1, C46.1, C47.1, C48.1, C49.1, C50.1, C51.1, C52.1, C53.1, C54.1, C55.1, C56.1, C57.1, C58.1, C59.1, C60.1, C61.1, C62.1, C63.1, C64.1, C65.1, C66.1, C67.1, C68.1, C69.1, C70.1, C71.1, C72.1, C73.1, C74.1, C75.1, C76.1, C77.1, C78.1, C79.1, C80.1, C81.1, C82.1, C83.1, C84.1, C85.1, C86.1, C87.1, C88.1, C89.1, C90.1, C91.1, C92.1, C93.1, C94.1, C95.1, C96.1, C97.1, C98.1, C99.1, C100.1, C101.1, C102.1, C103.1, C104.1, C105.1, C106.1, C107.1, C108.1, C109.1, C110.1, C111.1, C112.1, C113.1, C114.1, C115.1, C117.1, D1.1 (VDD), D2.1 (VDD), D3.1 (VDD), D4.1 (VDD), D5.1 (VDD), D6.1 (VDD), D7.1 (VDD), D8.1 (VDD), D9.1 (VDD), D10.1 (VDD), D11.1 (VDD), D12.1 (VDD), D13.1 (VDD), D14.1 (VDD), D15.1 (VDD), D16.1 (VDD), D17.1 (VDD), D18.1 (VDD), D19.1 (VDD), D20.1 (VDD), D21.1 (VDD), D22.1 (VDD), D23.1 (VDD), D24.1 (VDD), D25.1 (VDD), D26.1 (VDD), D27.1 (VDD), D28.1 (VDD), D29.1 (VDD), D30.1 (VDD), D31.1 (VDD), D32.1 (VDD), D33.1 (VDD), D34.1 (VDD), D35.1 (VDD), D36.1 (VDD), D37.1 (VDD), D38.1 (VDD), D39.1 (VDD), D40.1 (VDD), D41.1 (VDD), D42.1 (VDD), D43.1 (VDD), D44.1 (VDD), D45.1 (VDD), D46.1 (VDD), D47.1 (VDD), D48.1 (VDD), D49.1 (VDD), D50.1 (VDD), D51.1 (VDD), D52.1 (VDD), D53.1 (VDD), D54.1 (VDD), D55.1 (VDD), D56.1 (VDD), D57.1 (VDD), D58.1 (VDD), D59.1 (VDD), D60.1 (VDD), D61.1 (VDD), D62.1 (VDD), D63.1 (VDD), D64.1 (VDD), D65.1 (VDD), D66.1 (VDD), D67.1 (VDD), D68.1 (VDD), D69.1 (VDD), D70.1 (VDD), D71.1 (VDD), D72.1 (VDD), D73.1 (VDD), D74.1 (VDD), D75.1 (VDD), D76.1 (VDD), D77.1 (VDD), D78.1 (VDD), D79.1 (VDD), D80.1 (VDD), D81.1 (VDD), D82.1 (VDD), D83.1 (VDD), D84.1 (VDD), D85.1 (VDD), D86.1 (VDD), D87.1 (VDD), D88.1 (VDD), D89.1 (VDD), D90.1 (VDD), D91.1 (VDD), D92.1 (VDD), D93.1 (VDD), D94.1 (VDD), D95.1 (VDD), D96.1 (VDD), D97.1 (VDD), D98.1 (VDD), D99.1 (VDD), D100.1 (VDD), D101.1 (VDD), D102.1 (VDD), D103.1 (VDD), D104.1 (VDD), D105.1 (VDD), D106.1 (VDD), D107.1 (VDD), D108.1 (VDD), D109.1 (VDD), D110.1 (VDD), D111.1 (VDD), D112.1 (VDD), D113.1 (VDD), D114.1 (VDD), U1.14 (VBUS), U2.5 (VCC)
/LED_Data_3V3: U1.4 (D3), U2.2
GND: C1.2, C2.2, C3.2, C4.2, C5.2, C6.2, C7.2, C8.2, C9.2, C10.2, C11.2, C12.2, C13.2, C14.2, C15.2, C16.2, C17.2, C18.2, C19.2, C20.2, C21.2, C22.2, C23.2, C24.2, C25.2, C26.2, C27.2, C28.2, C29.2, C30.2, C31.2, C32.2, C33.2, C34.2, C35.2, C36.2, C37.2, C38.2, C39.2, C40.2, C41.2, C42.2, C43.2, C44.2, C45.2, C46.2, C47.2, C48.2, C49.2, C50.2, C51.2, C52.2, C53.2, C54.2, C55.2, C56.2, C57.2, C58.2, C59.2, C60.2, C61.2, C62.2, C63.2, C64.2, C65.2, C66.2, C67.2, C68.2, C69.2, C70.2, C71.2, C72.2, C73.2, C74.2, C75.2, C76.2, C77.2, C78.2, C79.2, C80.2, C81.2, C82.2, C83.2, C84.2, C85.2, C86.2, C87.2, C88.2, C89.2, C90.2, C91.2, C92.2, C93.2, C94.2, C95.2, C96.2, C97.2, C98.2, C99.2, C100.2, C101.2, C102.2, C103.2, C104.2, C105.2, C106.2, C107.2, C108.2, C109.2, C110.2, C111.2, C112.2, C113.2, C114.2, C115.2, C116.2, C117.2, D1.3 (VSS), D2.3 (VSS), D3.3 (VSS), D4.3 (VSS), D5.3 (VSS), D6.3 (VSS), D7.3 (VSS), D8.3 (VSS), D9.3 (VSS), D10.3 (VSS), D11.3 (VSS), D12.3 (VSS), D13.3 (VSS), D14.3 (VSS), D15.3 (VSS), D16.3 (VSS), D17.3 (VSS), D18.3 (VSS), D19.3 (VSS), D20.3 (VSS), D21.3 (VSS), D22.3 (VSS), D23.3 (VSS), D24.3 (VSS), D25.3 (VSS), D26.3 (VSS), D27.3 (VSS), D28.3 (VSS), D29.3 (VSS), D30.3 (VSS), D31.3 (VSS), D32.3 (VSS), D33.3 (VSS), D34.3 (VSS), D35.3 (VSS), D36.3 (VSS), D37.3 (VSS), D38.3 (VSS), D39.3 (VSS), D40.3 (VSS), D41.3 (VSS), D42.3 (VSS), D43.3 (VSS), D44.3 (VSS), D45.3 (VSS), D46.3 (VSS), D47.3 (VSS), D48.3 (VSS), D49.3 (VSS), D50.3 (VSS), D51.3 (VSS), D52.3 (VSS), D53.3 (VSS), D54.3 (VSS), D55.3 (VSS), D56.3 (VSS), D57.3 (VSS), D58.3 (VSS), D59.3 (VSS), D60.3 (VSS), D61.3 (VSS), D62.3 (VSS), D63.3 (VSS), D64.3 (VSS), D65.3 (VSS), D66.3 (VSS), D67.3 (VSS), D68.3 (VSS), D69.3 (VSS), D70.3 (VSS), D71.3 (VSS), D72.3 (VSS), D73.3 (VSS), D74.3 (VSS), D75.3 (VSS), D76.3 (VSS), D77.3 (VSS), D78.3 (VSS), D79.3 (VSS), D80.3 (VSS), D81.3 (VSS), D82.3 (VSS), D83.3 (VSS), D84.3 (VSS), D85.3 (VSS), D86.3 (VSS), D87.3 (VSS), D88.3 (VSS), D89.3 (VSS), D90.3 (VSS), D91.3 (VSS), D92.3 (VSS), D93.3 (VSS), D94.3 (VSS), D95.3 (VSS), D96.3 (VSS), D97.3 (VSS), D98.3 (VSS), D99.3 (VSS), D100.3 (VSS), D101.3 (VSS), D102.3 (VSS), D103.3 (VSS), D104.3 (VSS), D105.3 (VSS), D106.3 (VSS), D107.3 (VSS), D108.3 (VSS), D109.3 (VSS), D110.3 (VSS), D111.3 (VSS), D112.3 (VSS), D113.3 (VSS), D114.3 (VSS), U1.13 (GND), U2.1, U2.3 (GND), U3.3 (GND)
I2C_SCL: R3.2, U1.6 (D5), U3.1 (SCL)
I2C_SDA: R2.2, U1.5 (D4), U3.6 (SDA)
unnamed: D1.4 (DIN), R1.1
unnamed: D1.2 (DOUT), D2.4 (DIN)
unnamed: D2.2 (DOUT), D3.4 (DIN)
unnamed: D3.2 (DOUT), D4.4 (DIN)
unnamed: D4.2 (DOUT), D5.4 (DIN)
unnamed: D5.2 (DOUT), D6.4 (DIN)
unnamed: D6.2 (DOUT), D7.4 (DIN)
unnamed: D7.2 (DOUT), D8.4 (DIN)
unnamed: D8.2 (DOUT), D9.4 (DIN)
unnamed: D9.2 (DOUT), D10.4 (DIN)
unnamed: D10.2 (DOUT), D11.4 (DIN)
unnamed: D11.2 (DOUT), D12.4 (DIN)
unnamed: D12.2 (DOUT), D13.4 (DIN)
unnamed: D13.2 (DOUT), D14.4 (DIN)
unnamed: D14.2 (DOUT), D15.4 (DIN)
unnamed: D15.2 (DOUT), D16.4 (DIN)
unnamed: D16.2 (DOUT), D17.4 (DIN)
unnamed: D17.2 (DOUT), D18.4 (DIN)
unnamed: D18.2 (DOUT), D19.4 (DIN)
unnamed: D19.2 (DOUT), D20.4 (DIN)
unnamed: D20.2 (DOUT), D21.4 (DIN)
unnamed: D21.2 (DOUT), D22.4 (DIN)
unnamed: D22.2 (DOUT), D23.4 (DIN)
unnamed: D23.2 (DOUT), D24.4 (DIN)
unnamed: D24.2 (DOUT), D25.4 (DIN)
unnamed: D25.2 (DOUT), D26.4 (DIN)
unnamed: D26.2 (DOUT), D27.4 (DIN)
unnamed: D27.2 (DOUT), D28.4 (DIN)
unnamed: D28.2 (DOUT), D29.4 (DIN)
unnamed: D29.2 (DOUT), D30.4 (DIN)
unnamed: D30.2 (DOUT), D31.4 (DIN)
unnamed: D31.2 (DOUT), D32.4 (DIN)
unnamed: D32.2 (DOUT), D33.4 (DIN)
unnamed: D33.2 (DOUT), D34.4 (DIN)
unnamed: D34.2 (DOUT), D35.4 (DIN)
unnamed: D35.2 (DOUT), D36.4 (DIN)
unnamed: D36.2 (DOUT), D37.4 (DIN)
unnamed: D37.2 (DOUT), D38.4 (DIN)
unnamed: D38.2 (DOUT), D39.4 (DIN)
unnamed: D39.2 (DOUT), D40.4 (DIN)
unnamed: D40.2 (DOUT), D41.4 (DIN)
unnamed: D41.2 (DOUT), D42.4 (DIN)
unnamed: D42.2 (DOUT), D43.4 (DIN)
unnamed: D43.2 (DOUT), D44.4 (DIN)
unnamed: D44.2 (DOUT), D45.4 (DIN)
unnamed: D45.2 (DOUT), D46.4 (DIN)
unnamed: D46.2 (DOUT), D47.4 (DIN)
unnamed: D47.2 (DOUT), D48.4 (DIN)
unnamed: D48.2 (DOUT), D49.4 (DIN)
unnamed: D49.2 (DOUT), D50.4 (DIN)
unnamed: D50.2 (DOUT), D51.4 (DIN)
unnamed: D51.2 (DOUT), D52.4 (DIN)
unnamed: D52.2 (DOUT), D53.4 (DIN)
unnamed: D53.2 (DOUT), D54.4 (DIN)
unnamed: D54.2 (DOUT), D55.4 (DIN)
unnamed: D55.2 (DOUT), D56.4 (DIN)
unnamed: D56.2 (DOUT), D57.4 (DIN)
unnamed: D57.2 (DOUT), D58.4 (DIN)
unnamed: D58.2 (DOUT), D59.4 (DIN)
unnamed: D59.2 (DOUT), D60.4 (DIN)
unnamed: D60.2 (DOUT), D61.4 (DIN)
unnamed: D61.2 (DOUT), D62.4 (DIN)
unnamed: D62.2 (DOUT), D63.4 (DIN)
unnamed: D63.2 (DOUT), D64.4 (DIN)
unnamed: D64.2 (DOUT), D65.4 (DIN)
unnamed: D65.2 (DOUT), D66.4 (DIN)
unnamed: D66.2 (DOUT), D67.4 (DIN)
unnamed: D67.2 (DOUT), D68.4 (DIN)
unnamed: D68.2 (DOUT), D69.4 (DIN)
unnamed: D69.2 (DOUT), D70.4 (DIN)
unnamed: D70.2 (DOUT), D71.4 (DIN)
unnamed: D71.2 (DOUT), D72.4 (DIN)
unnamed: D72.2 (DOUT), D73.4 (DIN)
unnamed: D73.2 (DOUT), D74.4 (DIN)
unnamed: D74.2 (DOUT), D75.4 (DIN)
unnamed: D75.2 (DOUT), D76.4 (DIN)
unnamed: D76.2 (DOUT), D77.4 (DIN)
unnamed: D77.2 (DOUT), D78.4 (DIN)
unnamed: D78.2 (DOUT), D79.4 (DIN)
unnamed: D79.2 (DOUT), D80.4 (DIN)
unnamed: D80.2 (DOUT), D81.4 (DIN)
unnamed: D81.2 (DOUT), D82.4 (DIN)
unnamed: D82.2 (DOUT), D83.4 (DIN)
unnamed: D83.2 (DOUT), D84.4 (DIN)
unnamed: D84.2 (DOUT), D85.4 (DIN)
unnamed: D85.2 (DOUT), D86.4 (DIN)
unnamed: D86.2 (DOUT), D87.4 (DIN)
unnamed: D87.2 (DOUT), D88.4 (DIN)
unnamed: D88.2 (DOUT), D89.4 (DIN)
unnamed: D89.2 (DOUT), D90.4 (DIN)
unnamed: D90.2 (DOUT), D91.4 (DIN)
unnamed: D91.2 (DOUT), D92.4 (DIN)
unnamed: D92.2 (DOUT), D93.4 (DIN)
unnamed: D93.2 (DOUT), D94.4 (DIN)
unnamed: D94.2 (DOUT), D95.4 (DIN)
unnamed: D95.2 (DOUT), D96.4 (DIN)
unnamed: D96.2 (DOUT), D97.4 (DIN)
unnamed: D97.2 (DOUT), D98.4 (DIN)
unnamed: D98.2 (DOUT), D99.4 (DIN)
unnamed: D99.2 (DOUT), D100.4 (DIN)
unnamed: D100.2 (DOUT), D101.4 (DIN)
unnamed: D101.2 (DOUT), D102.4 (DIN)
unnamed: D102.2 (DOUT), D103.4 (DIN)
unnamed: D103.2 (DOUT), D104.4 (DIN)
unnamed: D104.2 (DOUT), D105.4 (DIN)
unnamed: D105.2 (DOUT), D106.4 (DIN)
unnamed: D106.2 (DOUT), D107.4 (DIN)
unnamed: D107.2 (DOUT), D108.4 (DIN)
unnamed: D108.2 (DOUT), D109.4 (DIN)
unnamed: D109.2 (DOUT), D110.4 (DIN)
unnamed: D110.2 (DOUT), D111.4 (DIN)
unnamed: D111.2 (DOUT), D112.4 (DIN)
unnamed: D112.2 (DOUT), D113.4 (DIN)
unnamed: D113.2 (DOUT), D114.4 (DIN)
unnamed: R1.2, U2.4

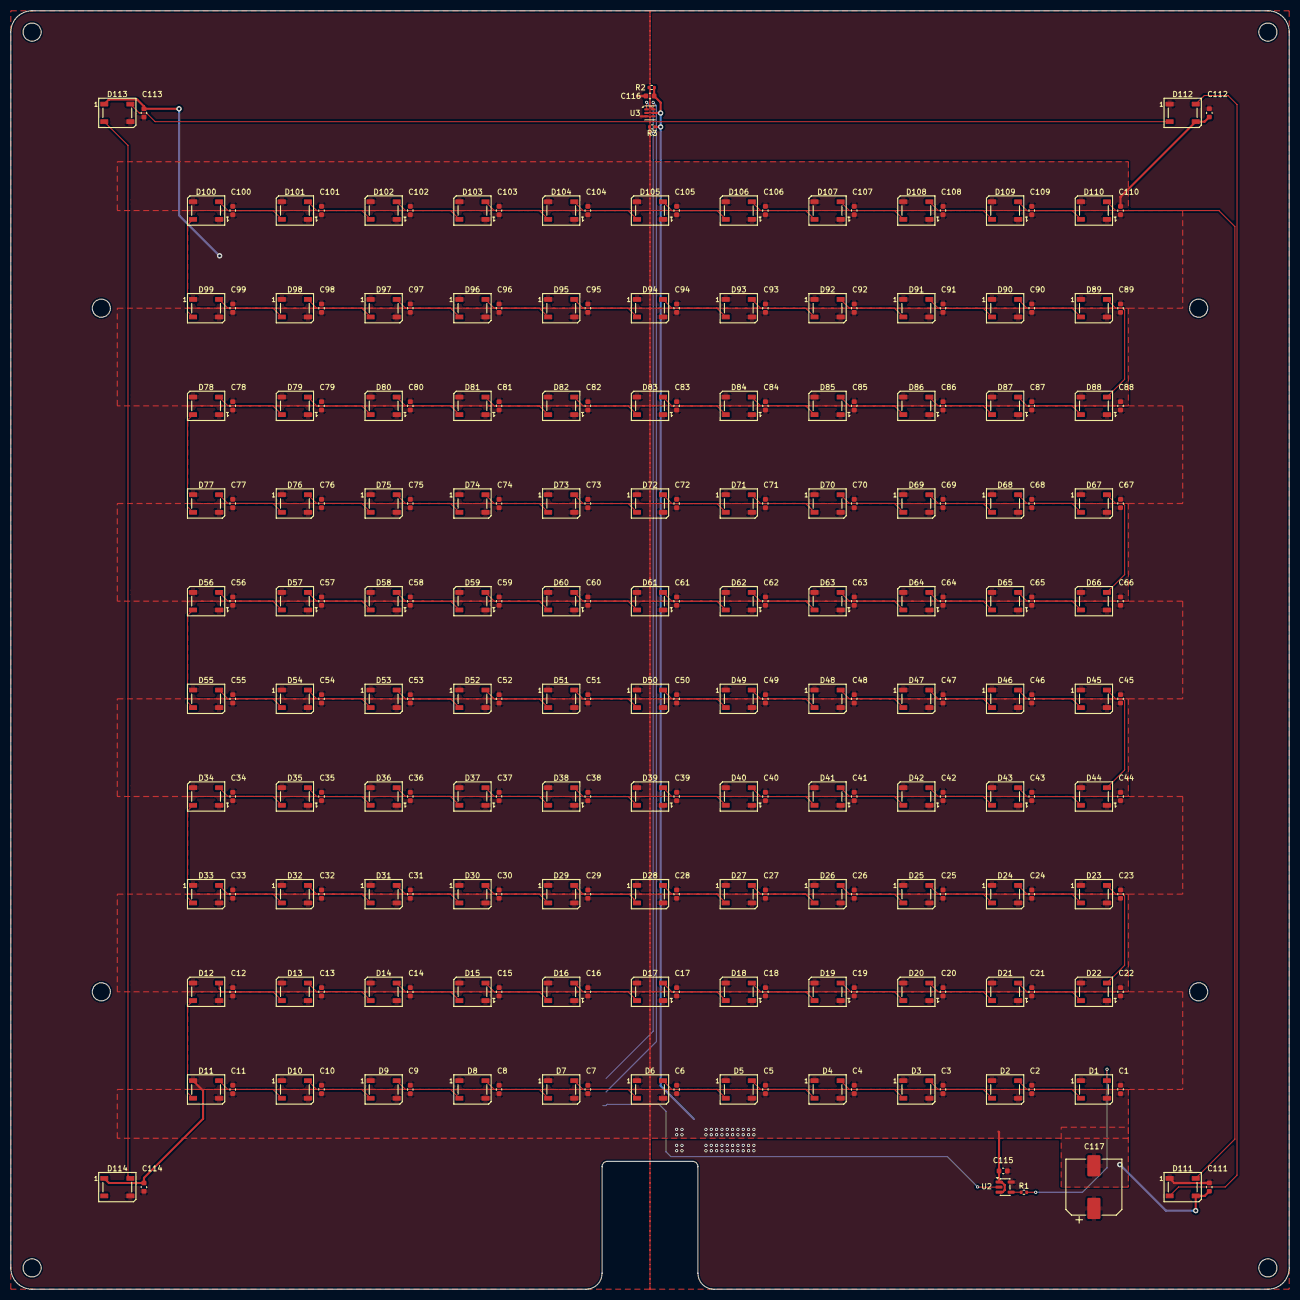
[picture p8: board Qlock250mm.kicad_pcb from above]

Board: 2 copper layers, 240.0 x 240.0 mm, 237 parts (1 on the bottom side), 121 nets.

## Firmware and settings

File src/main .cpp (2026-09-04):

/**
 * QlockThreeW32
 * Main program of the word clock: drives the LED matrix, keeps the time in sync
 * over NTP and serves the configuration web UI from LittleFS.
 *
 * @mc       ESP32S3
 * @author   Franz Kugler / franz _AT_ franz _MINUS_ kugler _DOT_ de
 * @version  2.0
 * @created  15.8.2026
 * @updated  15.8.2026
 *
 * Version history:
 * V 2.0:  - Consolidated for ESP32-S3 / WS2812B, comments translated to English.
 */
#include <Arduino.h>
#include <LittleFS.h>

#include <WiFi.h>
#include <ESPmDNS.h>
#include <WebServer.h>
#include <uri/UriBraces.h>
#include <esp_wifi.h>             // reading back stored credentials before connecting

// over the air updates
#include <ArduinoOTA.h>           // flashing from PlatformIO over the network
#include <Update.h>               // writing an image uploaded through the web UI
#include <HTTPClient.h>           // fetching the manifest and the images
#include <WiFiClientSecure.h>
#include <mbedtls/sha256.h>       // checking a download against the manifest
#include <esp_ota_ops.h>          // which slot we are running from

// debug library, and the in-memory ring the debug tab reads it out of
#include "LogBuffer.h"           //RemoteDebug: https://github.com/JoaoLopesF/RemoteDebug

// needed for NTP
#include <TimeLib.h>
#include <Timezone.h>               // https://github.com/JChristensen/Timezone
#include <esp_sntp.h>               // the core's own SNTP client, see below

// JSON library
#include "ArduinoJson.h"

#include "LedDriverWS2812FastLED.h"
#include "Renderer.h"
#include "Settings.h"
#include "LightSensor.h"
#include "Luminance.h"
#include "FactoryLuminance.h"
#include "Coupling.h"
#include "Calibration.h"
#include "OtaUpdate.h"
#include "Portal.h"
#include "DisplayModes.h"
#include "WebRoutes.h"
#include "FileRoutes.h"
#include "NvsRoutes.h"
#include "LabRoutes.h"
#include "Expert.h"
#include "languages/Language.h"
// Credentials of this particular clock, not in version control. Without it the
// build still works; see Secrets.example.h.
#if __has_include("Secrets.h")
#include "Secrets.h"
#endif
#include "Version.h"
#include "Zahlen.h"

#define WAIT_BEFORE_SETTINGS_WRITE 20

// Remote Debug server. A subclass, so that everything said through it lands
// in the ring as well - see LogBuffer.h.
DebugLog Debug;

// NTP specific values (not needed anymore)
int8_t timeZone = 0; //1
int8_t minutesTimeZone = 0;

// Central European Time (Frankfurt, Paris) to start with
TimeChangeRule CEST = {"CEST", Last, Sun, Mar, 2, 120};     // Central European Summer Time
TimeChangeRule CET = {"CET ", Last, Sun, Oct, 3, 60};       // Central European Standard Time

Timezone ActiveTimezone(CEST, CET);
String NTPServerName = String("pool.ntp.org");

// ------ Time synchronisation ------
// The core's SNTP client keeps the system clock in UTC; TimeLib reads it
// through the sync provider below, and the Timezone rules turn UTC into local
// time where it is displayed. NtpClientLib used to do this, but it depends on
// an old release of the Time library whose deprecated Time.h shadows <time.h>
// for every other source in the build, which made HTTPClient impossible to
// compile.

// A system clock still sitting near the epoch has never been set. Anything
// after 2023-11 is a real time.
#define TIME_LOOKS_VALID 1700000000

// Set from the SNTP callback, which runs in another task - hence volatile.
volatile time_t ntpLastSync = 0;
volatile bool ntpSyncPending = false;

bool wifiConnected = false;
bool wifiFirstConnected = true;

// Set web server port number to 80
WebServer server(80);

// Variable to store the HTTP request
String header;

// The persistent settings, stored in flash.
Settings settings;

// Measures the ambient light in the background. Nothing regulates on it yet -
// it is reported through /light so the sensor's placement behind the front
// panel can be judged before a curve is designed around it.
AmbientLight ambientLight;

// The renderer that puts the words onto the matrix.
Renderer renderer;

// LED driver. A value here has no effect - it has to be a constant in LedDriverWS2812FastLED.
LedDriverWS2812FastLED ledDriver;

// The light sensor

// mark for initial update
bool needsUpdateFromRtc = true;

// What last reached the LED driver, published through /light and /luminance.
// Without it the workbench could say what the curve wants and what the sensor
// sees, but not what the clock is actually doing - which is the one number
// somebody comparing the wall against the screen needs, and the one that was
// missing when the automatic first felt wrong.
byte appliedBrightness = 0;

#define WIFISTATUS_OFF   0
#define WIFISTATUS_GREEN 1
#define WIFISTATUS_RED   2


// Startmode...
byte mode = STD_MODE_NORMAL;

// The matrix, a kind of frame buffer
word matrix[16];

// Current column during the display test
byte x=0;

// some time markers
time_t lastTick;            // to trigger every second
time_t timeToSaveToFLASH;   // time when we have to save settings to the eeprom

// Transmit power. The part comes up at its maximum, 19.5 dBm, and a transmit
// burst at that level pulls 350-500 mA for a moment. A board fed through a USB
// cable, with a strip of 114 WS2812B on the same 5 V, does not always have that
// to give: the 3.3 V rail dips, the radio drops out mid-burst, and what you see
// is an access point that appears for a second and is gone again - a symptom
// that looks like anything except a supply problem.
//
// 13 dBm is 6 dB down, a quarter of the power, and still far more than a room
// needs. Raise it if the clock ends up somewhere with a weak signal; that is
// the trade this number makes.
#define WIFI_TX_POWER WIFI_POWER_13dBm

/**
 * Sets the transmit power on whichever interface has just come up.
 *
 * It has to be done per interface and after that interface has started, not
 * once in setup(): the value lives in the driver and starting STA or AP puts it
 * back to the maximum. Hence the call from the event handler, which is the only
 * place that knows the radio is up.
 */
static void applyTxPower(const char *which)
{
    WiFi.setTxPower(WIFI_TX_POWER);
    debugI("%s: Sendeleistung auf %.1f dBm gesetzt", which,
           WiFi.getTxPower() * 0.25f);
}

/**
 * Asks for the deferred settings write.
 *
 * Writing on every request would cost a flash erase per slider move, so
 * changes are collected and written WAIT_BEFORE_SETTINGS_WRITE seconds after
 * the last one. Exposed as a function because OtaUpdate has to ask for it too,
 * and that module should not have to know the delay.
 */
void scheduleSettingsSave()
{
    timeToSaveToFLASH = now() + WAIT_BEFORE_SETTINGS_WRITE;
}

// ------ WIFI connection functions ------

// How long the very first connection attempt at boot is given before it
// counts as failed and the setup portal takes over. Matches DoorOpener's own
// constant of the same name and purpose.
#define WIFI_BOOT_TIMEOUT 20000

/**
 * Tries the network the driver already knows about.
 *
 * The credentials are the WiFi driver's own, in its own NVS namespace: they
 * are put there by WiFi.begin(ssid, pass) - from the setup portal or from the
 * WLAN tab - and read back by WiFi.begin() with no arguments. Keeping a second
 * copy in this project's settings was the obvious alternative and is worse:
 * two stores of the same secret that can disagree, and the driver would still
 * hold the one that actually decides.
 *
 * @return true when connected; false when there was nothing to try or it did
 *         not come up in time. `hadCredentials` says which of the two.
 */
static bool connectStoredNetwork(bool &hadCredentials)
{
    WiFi.mode(WIFI_STA);
    // The name the router lists the clock under. Only read while the
    // interface comes up, so it has to be set before the connection is made.
    WiFi.setHostname(settings.getHostname());
    // Off, or the radio parks itself between beacons and the web UI answers
    // half a second late for no gain on a mains-powered clock.
    WiFi.setSleep(false);

    // Asked of the driver rather than inferred from what WiFi.begin() returns:
    // before the first attempt WiFi.SSID() is empty whether or not anything is
    // stored, and the difference decides between "start the portal and stay
    // there" and "start the portal but retry in ten minutes".
    wifi_config_t stored;
    hadCredentials = esp_wifi_get_config(WIFI_IF_STA, &stored) == ESP_OK &&
                     stored.sta.ssid[0] != '\0';
    if (!hadCredentials)
    {
        debugA("No stored network");
        return false;
    }

    debugA("Connecting to %s", (const char *)stored.sta.ssid);
    WiFi.begin();

    unsigned long deadline = millis() + WIFI_BOOT_TIMEOUT;
    while (WiFi.status() != WL_CONNECTED && (long)(millis() - deadline) < 0)
    {
        delay(250);
    }

    if (WiFi.status() != WL_CONNECTED)
    {
        debugW("Could not reach %s within %d s", WiFi.SSID().c_str(), WIFI_BOOT_TIMEOUT / 1000);
        return false;
    }

    debugA("Connected - local IP %s", WiFi.localIP().toString().c_str());
    return true;
}

void WiFiEvent(WiFiEvent_t event, WiFiEventInfo_t info)
{
    debugI("[WiFi-event] event: %d", event);

    switch (event) {
        case ARDUINO_EVENT_WIFI_READY: 
            debugI("WiFi interface ready");
            break;
        case ARDUINO_EVENT_WIFI_SCAN_DONE:
            debugI("Completed scan for access points");
            break;
        case ARDUINO_EVENT_WIFI_STA_START:
            applyTxPower("STA");
            debugI("WiFi client started");
            break;
        case ARDUINO_EVENT_WIFI_STA_STOP:
            debugI("WiFi clients stopped");
            break;
        case ARDUINO_EVENT_WIFI_STA_CONNECTED:
            debugI("Connected to access point %s", (char*)info.wifi_sta_connected.ssid);
            break;
        case ARDUINO_EVENT_WIFI_STA_DISCONNECTED:
            debugW("Disconnected from SSID: %s", (char*)info.wifi_sta_disconnected.ssid);
            debugW("Reason: %d", (int)event);
            // SNTP is left running: it retries by itself once the network is
            // back, and the system clock keeps counting in the meantime.
            wifiConnected = false;
            break;
        case ARDUINO_EVENT_WIFI_STA_AUTHMODE_CHANGE:
            debugI("Authentication mode of access point has changed");
            break;
        case ARDUINO_EVENT_WIFI_STA_GOT_IP:
            debugI("Obtained IP address: %s", WiFi.localIP().toString().c_str());
            debugI("Connected: %s", WiFi.status () == WL_CONNECTED ? "yes" : "no");
            wifiConnected = true;            
            break;
        case ARDUINO_EVENT_WIFI_STA_LOST_IP:
            debugI("Lost IP address and IP address is reset to 0");
            break;
        case ARDUINO_EVENT_WPS_ER_SUCCESS:
            debugI("WiFi Protected Setup (WPS): succeeded in enrollee mode");
            break;
        case ARDUINO_EVENT_WPS_ER_FAILED:
            debugI("WiFi Protected Setup (WPS): failed in enrollee mode");
            break;
        case ARDUINO_EVENT_WPS_ER_TIMEOUT:
            debugI("WiFi Protected Setup (WPS): timeout in enrollee mode");
            break;
        case ARDUINO_EVENT_WPS_ER_PIN:
            debugI("WiFi Protected Setup (WPS): pin code in enrollee mode");
            break;
        case ARDUINO_EVENT_WIFI_AP_START:
            applyTxPower("AP");
            debugI("WiFi access point started");
            break;
        case ARDUINO_EVENT_WIFI_AP_STOP:
            debugI("WiFi access point  stopped");
            break;
        case ARDUINO_EVENT_WIFI_AP_STACONNECTED:
            debugI("Client connected");
            break;
        case ARDUINO_EVENT_WIFI_AP_STADISCONNECTED:
            debugI("Client disconnected");
            break;
        case ARDUINO_EVENT_WIFI_AP_STAIPASSIGNED:
            debugI("Assigned IP address to client");
            break;
        case ARDUINO_EVENT_WIFI_AP_PROBEREQRECVED:
            debugI("Received probe request");
            break;
        case ARDUINO_EVENT_WIFI_AP_GOT_IP6:
            debugI("AP IPv6 is preferred");
            break;
        case ARDUINO_EVENT_WIFI_STA_GOT_IP6:
            debugI("STA IPv6 is preferred");
            break;
        case ARDUINO_EVENT_ETH_GOT_IP6:
            debugI("Ethernet IPv6 is preferred");
            break;
        case ARDUINO_EVENT_ETH_START:
            debugI("Ethernet started");
            break;
        case ARDUINO_EVENT_ETH_STOP:
            debugI("Ethernet stopped");
            break;
        case ARDUINO_EVENT_ETH_CONNECTED:
            debugI("Ethernet connected");
            break;
        case ARDUINO_EVENT_ETH_DISCONNECTED:
            debugI("Ethernet disconnected");
            break;
        case ARDUINO_EVENT_ETH_GOT_IP:
            debugI("Obtained IP address");
            break;
        default: break;
    }
}

// ------ NTP functions ------

/**
 * Where TimeLib gets its time from. Returning 0 leaves timeStatus() at
 * timeNotSet, which is what we want until SNTP has answered for the first time
 * - otherwise the clock would confidently display 1970.
 */
time_t syncFromSystemClock()
{
    time_t systemTime = time(nullptr);
    return systemTime > TIME_LOOKS_VALID ? systemTime : 0;
}

/** Called by the SNTP task whenever it has set the system clock. */
void onNtpSync(struct timeval *received)
{
    ntpLastSync = received->tv_sec;
    ntpSyncPending = true;
}

/**
 * Points SNTP at the configured server. Safe to call again later: that is how
 * a server changed through the web UI takes effect.
 */
void startNtp()
{
    // UTC, both offsets zero - the Timezone rules do the local conversion.
    configTime(0, 0, NTPServerName.c_str());
    debugI("SNTP started, server %s", NTPServerName.c_str());
}

bool isKnownMode(byte candidate)
{
    switch (candidate)
    {
        case STD_MODE_BLANK:   // and STD_MODE_NIGHT, which is the same number
        case STD_MODE_NORMAL:
        case STD_MODE_SECONDS:
        case EXT_MODE_TEST:
        case EXT_MODE_NORMAL_WIFISTATUS:
            return true;
        default:
            return false;
    }
}

TimeChangeRule tzRuleFrom(const char* abbrev, uint8_t week, uint8_t dow,
                          uint8_t month, uint8_t hour, int offset)
{
    TimeChangeRule rule;
    // abbrev holds five characters plus the terminator, while the settings
    // field is wider - so copy defensively rather than assume it fits.
    strncpy(rule.abbrev, abbrev, sizeof(rule.abbrev) - 1);
    rule.abbrev[sizeof(rule.abbrev) - 1] = '\0';
    rule.week = week;
    rule.dow = dow;
    rule.month = month;
    rule.hour = hour;
    rule.offset = offset;
    return rule;
}

/** In the order of the LANGUAGE_* defines, for the log line below. */
static const char *LANGUAGE_NAMES[] = {
    "DE", "DE-SW", "DE-BA", "DE-SA", "CH", "EN", "FR", "IT", "NL", "ES"
};
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
void loop()
{
    // A restart is pending - after an update, or after a rename. Nothing else
    // may run in the meantime, because on a filesystem update LittleFS is
    // unmounted underneath us.
    //
    // The settings are the exception, and they have to be: they are what the
    // deferred write still owes, and skipping it loses every change made in
    // the twenty seconds before the restart. That used to be the right call
    // when they lived in qlockconf.json, where writing would have landed in
    // the image just flashed. They live in NVS now, in a partition no update
    // touches, so flushing here is safe.
    if (Ota::restartPending())
    {
        if (Ota::restartDue())
        {
            if (timeToSaveToFLASH != std::numeric_limits<time_t>::max())
            {
                debugA("Flushing pending settings before the restart");
                settings.storeSettings();
            }
            debugA("Restarting");
            server.stop();
            ESP.restart();
        }
        return;
    }

    // The setup portal is up instead of normal operation - see Portal.h.
    // Nothing below this may run: the WiFi reconnect a few lines down would
    // fight the portal's own AP+DNS state, and nothing else here is even
    // registered on the server yet.
    if (Portal::active())
    {
        Portal::poll();
        server.handleClient();
        return;
    }

    // drive a network switch requested through the web UI
    Web::poll();

    // this is to check if we have a connection to the WLAN
    // (skipped while switching networks, which manages the connection itself)
    if (!wifiConnected && !Web::switchingNetwork())
    {
        debugI("Wifi lost");
        // we hopefully have a valid SSID stored
        if (WiFi.SSID()) 
        {
            WiFi.begin();
            // wait if we get a connection
            if (WiFi.waitForConnectResult() == WL_CONNECTED)
            {
                // success - yeah!
                debugI("Reconnected - yeah!!!!");
                wifiConnected = true;
                wifiFirstConnected = true; 
            }
        }
    }
    
    // check if we have to get the time for the first time
    if (wifiConnected && wifiFirstConnected) 
    {
        debugI("wifiFirstConnected");
        wifiFirstConnected = false;
        // re-activate Web Server
        server.begin();
        
        // re-activate Over The Air functionality
        //ArduinoOTA.setHostname("QlockThreeW32");
        //ArduinoOTA.begin();
        
        // get time again - now from the server the settings name, where the
        // old code always asked pool.ntp.org whatever was configured
        startNtp();

        // update the display too
        needsUpdateFromRtc = true;
    }

    // Periodic check of the release channel, and the automatic install if it
    // is switched on. The local hour decides the night window; a negative one
    // says the time is not known yet, before the first NTP answer.
    Ota::poll(wifiConnected,
              timeStatus() == timeNotSet ? -1 : hour(ActiveTimezone.toLocal(now())));

    // this is true when SNTP has just set the system clock
    if (ntpSyncPending)
    {
        ntpSyncPending = false;
        debugI("Got NTP time, epoch %lu", (unsigned long)ntpLastSync);
    }

    // things to do when we have WiFi
    if (wifiConnected)
    {
        // let the webserver do its thing
        server.handleClient();
        
        // handle debug requests
        Debug.handle();
    
        // check if there is a firmware update on the line
        ArduinoOTA.handle();
    }

	// check if we have to update the display - set every second
    if (now() > lastTick)
    {
        lastTick = now();
        needsUpdateFromRtc = true;

        // Once a second is often enough for a ten second timer, and it keeps
        // the settle check on the same beat as everything else here.
        // The short average, not the one the regulator runs on: a point is a
        // statement about the light in the room now. See teachingLux().
        Luminance::poll(ambientLight.teachingLux());
    }
    
    // The lab owns the strip while a script is measuring, so the render loop
    // must not push a frame over what was just written - every reading would
    // otherwise be of the clock face rather than of the frame under test. The
    // flag is cleared all the same, so leaving lab mode redraws at once.
    if (Lab::active() || Calibration::running()) needsUpdateFromRtc = false;

	// we have to change something at the display
    if (needsUpdateFromRtc)
	{
		needsUpdateFromRtc = false;

        // convert time to correct timezone and store in actual. The rule that
        // applied comes back too, so the log below can name it - which is what
        // tells standard time from summer time at a glance.
        TimeChangeRule *activeRule = NULL;
        time_t actual = ActiveTimezone.toLocal(now(), &activeRule);

        // set color and brightness first
        // The only place the user's units meet FastLED's 8 bit ones. Rounded
        // rather than truncated, so the LEDs get the nearest hue the hardware
        // can actually produce - 360 hues do not fit into 256 steps.
        ledDriver.setColorHS((byte)((settings.getColorHue() * 255L + 179) / 359),
                             (byte)((settings.getColorSat() * 255L + 50) / 100));
        ledDriver.setBrightness(brightnessToApply());

        //
        // fill the frame buffer...
        //
        switch (mode)
        {
            case STD_MODE_BLANK:
            {
                renderer.clearScreenBuffer(matrix);
                break;
            }
            case STD_MODE_NORMAL:
            case EXT_MODE_NORMAL_WIFISTATUS:
            {
                debugV("Time %02d:%02d:%02d", hour(actual), minute(actual), second(actual));
                renderer.clearScreenBuffer(matrix);
                renderer.setMinutes(hour(actual), minute(actual), settings.getLanguage(), matrix);
                renderer.setCorners(minute(actual), settings.getRenderCornersCw(), matrix);
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

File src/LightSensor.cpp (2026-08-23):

/**
 * LightSensor
 * See LightSensor.h for what this is and why the sampling runs in a task.
 *
 * @mc       ESP32S3
 * @author   Franz Kugler / franz _AT_ franz _MINUS_ kugler _DOT_ de
 * @version  2.1
 * @created  17.8.2026
 * @updated  17.8.2026
 */
#include <Wire.h>
#include <Adafruit_VEML7700.h>
#include <Adafruit_TSL2591.h>

#include "LightSensor.h"

// Debug and the debugX macros, plus the ring the web UI reads them out of.
#include "LogBuffer.h"

// How often the sensor is asked. Ambient light does not change quickly and
// every reading costs an auto-ranging round, so this is deliberately slow.
#define SAMPLE_INTERVAL_MS 2000

// Time constant of the smoothing, in seconds. Someone walking past, a cloud,
// a door opening - none of that should reach the display, and a clock that
// visibly follows such things is the usual complaint about automatic
// brightness. Converted to an EMA weight from the sample interval below.
#define SMOOTHING_SECONDS 30.0f

// Time constant of the *teaching* average, which is a different question and
// therefore a different number.
//
// Regulating must not follow a passing shadow, so it averages over half a
// minute. Learning is somebody saying "at this light, I want this much" - and
// the light they mean is the one in the room now, not the one thirty seconds
// ago. The two collided in the field: the settle time before a point is kept
// is ten seconds, over which a 30 s average travels only 28 % of the way, so a
// correction made just after the light changed was stored against a reading
// the room no longer had. Measured on a real session: the room went to
// 0.0009 lx, the slider was set to 30 %, and the pair kept was 0.1184 lx ->
// 30 % - a light level 148 times too high, straight into the slope.
//
// Three seconds averages the sensor and has still arrived well inside the ten.
#define TEACHING_SECONDS 3.0f

// Enough for the Adafruit library and the I2C stack underneath it.
#define SAMPLE_TASK_STACK 4096


bool Veml7700Sensor::begin()
{
    Adafruit_VEML7700 *veml = new Adafruit_VEML7700();
    if (!veml->begin(&Wire))
    {
        delete veml;
        return false;
    }
    device = veml;
    return true;
}

/**
 * Passes a reading through, or refuses it.
 *
 * A NaN is not a small problem here. `lux < 0` is false for a NaN, so the old
 * guard let one straight through into the exponential average, where it stays
 * for ever - every later sample averaged against a NaN is a NaN, and the
 * automatic brightness would be stuck with no sign of why. calculateLux()
 * divides by CH0, so a genuinely dark room used to be enough to produce one:
 * /lab/sensor reported `lux: null` on the seven least sensitive rungs, which
 * is how this was found.
 */
static float sane(float lux)
{
    if (!isfinite(lux) || lux < 0.0f) return -1.0f;
    return lux;
}

float Veml7700Sensor::readLux()
{
    if (!device) return -1.0f;
    // Auto-ranging: picks gain and integration time, then applies Vishay's
    // correction for the non-linearity above roughly a thousand lux. Blocking,
    // which is why this is only ever called from the sampling task.
    return sane(((Adafruit_VEML7700 *)device)->readLux(VEML_LUX_AUTO));
}


// --- TSL2591 -------------------------------------------------------------
//
// The sensitivity ladder, least sensitive first. Gain carries the range - its
// steps are factors of 25, 17 and 23 - and integration time fills in between
// them with factors of 2 and 3. Written out as a list rather than computed from
// the two axes because not every combination is worth having: the 300 and
// 500 ms steps buy a third of a decade for a third of a second and are left
// out, and the low gains do not need the long times.
static const struct
{
    tsl2591Gain_t gain;
    tsl2591IntegrationTime_t time;
} LADDER[] = {
    { TSL2591_GAIN_LOW,  TSL2591_INTEGRATIONTIME_100MS },   // ~88 klx full scale
    { TSL2591_GAIN_LOW,  TSL2591_INTEGRATIONTIME_200MS },
    { TSL2591_GAIN_MED,  TSL2591_INTEGRATIONTIME_100MS },
    { TSL2591_GAIN_MED,  TSL2591_INTEGRATIONTIME_200MS },
    { TSL2591_GAIN_HIGH, TSL2591_INTEGRATIONTIME_100MS },
    { TSL2591_GAIN_HIGH, TSL2591_INTEGRATIONTIME_200MS },   // start here
    { TSL2591_GAIN_HIGH, TSL2591_INTEGRATIONTIME_400MS },
    { TSL2591_GAIN_MAX,  TSL2591_INTEGRATIONTIME_200MS },
    { TSL2591_GAIN_MAX,  TSL2591_INTEGRATIONTIME_400MS },
    { TSL2591_GAIN_MAX,  TSL2591_INTEGRATIONTIME_600MS },   // ~188 uLx resolution
};
#define LADDER_STEPS ((byte)(sizeof(LADDER) / sizeof(LADDER[0])))

// Where to start. In the middle, because either end is four steps from the
// other and there is no way to guess which end a given clock sits at before
// the first reading.
#define LADDER_START 5

// The ADC saturates at 36863 counts at 100 ms and at 65535 above it. Backing
// off at nine tenths of that keeps the reading out of the region where the
// two channels stop tracking each other and the lux calculation goes wrong.
#define SATURATED_FRACTION 0.9f

// Below this many counts the reading is mostly quantisation noise and the next
// rung up is worth the wait. Not zero: a handful of counts still carries
// information, and stepping up costs a whole sample interval.
#define TOO_FEW_COUNTS 80


bool Tsl2591Sensor::begin()
{
    Adafruit_TSL2591 *tsl = new Adafruit_TSL2591(2591);
    if (!tsl->begin(&Wire))
    {
        delete tsl;
        return false;
    }
    device = tsl;
    _rung = LADDER_START;
    applyRung();
    return true;
}

void Tsl2591Sensor::applyRung()
{
    if (!device) return;
    ((Adafruit_TSL2591 *)device)->setGain(LADDER[_rung].gain);
    ((Adafruit_TSL2591 *)device)->setTiming(LADDER[_rung].time);
}
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

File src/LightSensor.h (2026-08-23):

/**
 * LightSensor
 * Ambient light measurement.
 *
 * Two things live here. `LightSensor` is the interface a sensor has to satisfy
 * - one blocking reading in lux - so the part that matters can be swapped
 * without touching anything else. `Veml7700Sensor` is the one implementation
 * so far; a TSL2591 or an OPT3001 would be another class next to it and a
 * different line in `AmbientLight::begin()`.
 *
 * `AmbientLight` owns the sensor, samples it from a task of its own and
 * smooths the result. The task is not optional: auto-ranging on the VEML7700
 * changes gain and integration time and waits for a fresh measurement each
 * time, which can block for well over a second - and the clock's web server is
 * synchronous, so a blocked loop() is a clock that stops answering.
 *
 * What is done with the reading is not here. Luminance.h owns the curve from
 * lux to display brightness and how it is learned; this file measures, smooths
 * and stops. The two lived together for a while and the seam was worth cutting:
 * the curve is arithmetic that can be reasoned about at a desk, and the
 * measurement is a chip on a wire.
 *
 * @mc       ESP32S3
 * @author   Franz Kugler / franz _AT_ franz _MINUS_ kugler _DOT_ de
 * @version  2.1
 * @created  17.8.2026
 * @updated  17.8.2026
 */
#ifndef LIGHTSENSOR_H
#define LIGHTSENSOR_H

#include "Arduino.h"
#include <freertos/FreeRTOS.h>
#include <freertos/semphr.h>   // one bus, two tasks; see AmbientLight below

// The XIAO ESP32-S3 brings these out as D4 and D5 and the core already
// defaults to them; overridable because the firmware serves every build of the
// clock and the sensor does not sit in the same place in all of them.
#ifndef I2C_SDA_PIN
#define I2C_SDA_PIN 5
#endif
#ifndef I2C_SCL_PIN
#define I2C_SCL_PIN 6
#endif

// Readings below this are treated as darkness. The VEML7700 reports a plain 0
// in a closed room and log(0) has no answer, so the curve needs a floor - and
// a hundredth of a lux is far below anything the eye distinguishes anyway.
#define LUX_FLOOR 0.01f

/** One ambient light sensor, whichever chip it happens to be. */
class LightSensor
{
public:
    virtual ~LightSensor() {}

    /** Brings the chip up. False when it does not answer. */
    virtual bool begin() = 0;

    /** One measurement in lux, or a negative value when the read failed. */
    virtual float readLux() = 0;

    /** For the web UI, so it can say what it is talking to. */
    virtual const char *name() const = 0;

    // ------ what the lab interface needs, and nothing else uses ------
    //
    // Optional, because they are not things every chip can do. The default
    // answers say "not this one" rather than pretending, so a lab client can
    // ask and be told no instead of reading a number that means nothing.

    /**
     * The raw channel counts behind the last readLux().
     *
     * The point of having them is that the two channels see the world
     * differently: WS2812B put out almost no infrared, room light and daylight
     * put out plenty. If the infrared channel barely moves when the display
     * does, it is an ambient reading the clock cannot pollute - which is worth
     * a great deal on a clock whose sensor can see its own face.
     */
    virtual bool readChannels(uint16_t &full, uint16_t &infrared) { (void)full; (void)infrared; return false; }

    /** How many sensitivity steps this chip is driven through. 0 for none. */
    virtual uint8_t rungCount() const { return 0; }

    /** Where it is standing now. */
    virtual uint8_t rung() const { return 0; }

    /**
     * Pins the sensitivity, or -1 to let it range again.
     *
     * A measurement series wants this: auto-ranging changes gain and
     * integration time underneath a scan, and two readings taken on different
     * rungs are not comparable in counts, only in lux - and the lux
     * calculation is exactly what we are trying to check.
     */
    virtual bool pinRung(int8_t which) { (void)which; return false; }

    /** Integration time of the current rung, in milliseconds. */
    virtual uint16_t integrationMs() const { return 0; }
};

/**
 * Vishay VEML7700 on I2C, address 0x10 (fixed, so only one per bus).
 *
 * Reads through the library's auto-ranging mode, which walks gain and
 * integration time until the reading sits in a usable part of the range and
 * applies Vishay's correction for the non-linearity at the top end. That is
 * the whole reason for choosing this over the BH1750 that used to be here:
 * behind a dark front panel a lit living room can arrive as a handful of lux,
 * and the BH1750 resolves 1 lx.
 */
class Veml7700Sensor : public LightSensor
{
public:
    bool begin() override;
    float readLux() override;
    const char *name() const override { return "VEML7700"; }

private:
    void *device = nullptr; // Adafruit_VEML7700, kept out of the header
};
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

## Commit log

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2026-08-13 Consolidate firmware to a single hardware target (ESP32-S3 + WS2812B)
    The project used to support multiple ESP32 boards and (per Configuration.h)
    several alternate LED drivers, RTC chips, and other AVR-era peripherals
    that no longer applied to the current build. Reduced to the one board
    actually in use:
    - platformio.ini: keep only the seeed_xiao_esp32s3 environment; drop
    nodemcu-32s and esp32-c3-display, and the partition tables that only
    they referenced.
    - Remove Configuration.h, a large block of compile-time toggles for
    hardware this build never used, already unreferenced by any active
    code path.
    - Fold the LedDriver abstract base into LedDriverWS2812FastLED, its
    only implementa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
    [Configuration.h, min_spiffs.csv, partitions.csv]
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2026-08-13 Replace the jQuery config page with a Svelte SPA
    The web UI was a single jQuery page loading Bootstrap, FontAwesome,
    jQuery and iro.js from CDNs, so it rendered broken whenever the clock
    was reachable on the LAN but the LAN had no internet access.
    Rewrite it as a Svelte 5 + Vite SPA in web/, built into data/ for the
    LittleFS image (81 KB, 30 KB gzipped, against a 3.5 MB partition).
    Everything is bundled locally; the colour wheel is still iro.js, now a
    dependency instead of a CDN script. Styling is hand-written CSS that
    follows the system light/dark preference.
    The behaviour is carried over unchanged: same mode/language/corner
    values (the firmware's own numbers), immediate POST per change w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
    [main .cpp]
2026-08-13 Add a WLAN tab and restyle the WiFiManager portal
    WiFi was the one thing the config UI could not do: the network could
    only be changed through WiFiManager's captive portal, which looks
    nothing like the rest of the UI.
    Firmware gains three endpoints:
    - GET /wifi connection status
    - GET /wifi/scan one poll of an async scan
    - POST /wifi switch networks
    Switching is not a plain WiFi.begin(): a wrong password would leave the
    clock unreachable until someone power-cycles it and uses the AP portal.
    POST /wifi only records the request and answers immediately -- the
    response would never leave the old network otherwise -- and
    handleWifiSwitch() runs a state machine in loop(): try the n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
    [main .cpp]
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2026-08-15 Move the espota password out of the source
    Ahead of publishing the repository: OTA_PASSWORD now comes from src/Secrets.h,
    which is gitignored, with src/Secrets.example.h as the committed template.
    main .cpp includes it behind __has_include, so a fresh clone still builds - it
    gets a #warning and an unprotected espota instead of a compile error. Verified
    both ways.
    Also corrects two statements in CLAUDE.md that were simply wrong: ArduinoOTA
    listens on port 8266, not the ESP32 default 3232, and it is password-protected,
    so it is not the equally open door next to /ota/upload that the note claimed.
    [main .cpp]
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2026-08-15 Replace NtpClientLib with the core's own SNTP
    NtpClientLib declares a dependency on Time ~1.5, which the pinned 1.6.1 does
    not satisfy, so PlatformIO installed a second copy of the Time library. That
    old copy ships a deprecated Time.h, and every installed library folder lands on
    the include path of every source - so on a case-insensitive filesystem
    `#include <time.h>` inside the framework's HTTPClient.cpp resolved to Time.h
    and the build died on strptime, mktime and struct tm. Deleting the header broke
    the duplicate's own compilation; lib_ignore kept it out of the dependency graph
    but not off the include path, which I confirmed by reading the include list off
    the actual compiler invocation.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
    [main .cpp]
2026-08-16 Poll the release channel from the clock
    Step 2 of the update path: the clock now fetches the manifest of its channel,
    reports what is on offer and installs it on request.
    - otaFetchManifest() reads the manifest of the selected channel from one of two
    fixed URLs - the clock never touches the GitHub API.
    - otaInstallTask runs on core 0, so the synchronous web server on core 1 keeps
    answering and the UI can show progress during the ~40 s a transfer takes.
    Each image is streamed straight into its partition while being hashed, and
    the boot partition is only switched once the SHA-256 matches the manifest.
    Only the half whose version actually differs is fetched.
    - Version comparison diff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
    [main .cpp]
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2026-08-16 Restore the accents in the German, French, Spanish and Italian texts
    The locale files written first carried proper umlauts and accents; the keys
    added later by script were put in as ASCII transliterations to avoid encoding
    trouble in transit, and it shows - "Verfuegbar", "noch nicht geprueft",
    "pas encore verifie", "El reloj esta actualizado". Now spelled properly in all
    six locales, along with the ellipsis character the older strings already used.
    Verified at byte level rather than by eye: no replacement characters in any
    file, and the expected code points are present (ä ö ü ß in German, à â ç è é ê
    ô û in French, à è é ì ò ù in Italian, á é í ñ ó ú in Spanish).
    Le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
    [main .cpp]
2026-08-16 Report errors as codes so the UI can translate them
    The firmware answered with German sentences, which was fine while the UI was
    German too - with six languages it meant a Spanish UI reporting "Pruefsumme
    stimmt nicht". It now sends a stable code plus an untranslated detail
    ({"error": "otaChecksum", "errorDetail": "HTTP 404"}), and web/src/lib/errors.js
    turns that into text in the current language from the err_* keys.
    An unknown code is shown as-is rather than swallowed: a clock running newer
    firmware than its web UI should still say something searchable. That also means
    the already-translated network failures api.js raises pass through untouched,
    so both kinds of message go through one pat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
    [main .cpp]
2026-08-16 Store hue and saturation in the units the UI uses
    Setting 195/90/70 and rebooting gave 194/89/70 back. Not a rounding error in
    RGB - RGB is not involved. Settings kept hue and saturation scaled to a byte,
    so every value crossed two truncating integer divisions, one on the way in and
    one on the way out. Both round down, so the errors added up instead of
    cancelling: 358 of 360 hues came back wrong, by up to 2, and 95 of 101
    saturations by 1.
    The two halves of that were different problems. 360 hues genuinely do not fit
    in 256 steps. Saturation never had that excuse - 101 values into 256 slots is
    upsampling, and it was losing them purely to truncation.
    Both are stored in the UI's own units now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
    [main .cpp]
2026-08-16 Fix the OTA download, which timed out after 20 ms instead of 20 s
    client.setTimeout(20) was meant to allow twenty seconds and allowed twenty
    milliseconds. NetworkClientSecure inherits NetworkClient and neither
    overrides setTimeout; only NetworkServer has a seconds-based one. So the
    call fell through to Stream::setTimeout, which is documented in
    milliseconds.
    Twenty milliseconds is not enough for readBytes() to wait out the next TLS
    record of a multi-megabyte transfer. It returned 0, the loop treated that
    as the end of the stream and broke, and the size check then reported
    "otaSize" - "download incomplete" - on a download that was never at fault.
    Every install from the release channel failed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
    [main .cpp]
2026-08-16 Install the firmware before the filesystem, and restart on a rename
    Update is a singleton, and a second session in the same boot does not
    activate. Installing the filesystem first and the firmware after it got
    both images down intact - digests and all - and then failed in
    esp_ota_set_boot_partition() with "Could Not Activate The Firmware". The
    same firmware install on its own goes through, which is what isolated it.
    This way round the firmware gets the fresh session, and the filesystem,
    which needs no boot partition switched and only bytes written, gets the
    second.
    It is also the safer half to fail on. Update.begin(U_SPIFFS) erases the
    partition before the download starts, so an interrupted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
    [main .cpp]
2026-08-16 Persist the display mode, flush settings before a restart, log the face
    An audit of what the web UI shows against what survives a restart, prompted
    by a report that a timezone had not been saved. Every field was set to a
    distinctive value, given time for the deferred write, and the clock then
    hard reset over esptool - which writes nothing and calls no handler, so
    only what reached NVS came back.
    Exactly one field was lost: the display mode. `Mode` was reported in
    getJSONSettings() and set by /display, but appeared in neither
    fillDocument() nor loadSettings(), so it was decoration - "off (dark)" and
    "time with WiFi status" reverted to plain time on every restart. Now in
    both. The other twelv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
    [main .cpp]
2026-08-16 Free the TLS session before verifying an OTA image
    "Could Not Activate The Firmware" was blamed on Update being a singleton
    that will not activate in a second session, and the install order was
    swapped on that basis. The explanation was wrong: the failure then
    happened with the firmware going first as well, and the very next attempt
    - same firmware, same images, nothing changed - installed both halves and
    rebooted cleanly. Intermittent means resources, not order.
    http.end() closes the connection but leaves the mbedTLS context on the
    client, which is tens of kilobytes and lives until otaDownloadImage()
    returns - so it was still held while Update.end(true) ran
    esp_ota_set_boot_partition(), wh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
    [main .cpp]
2026-08-16 Name the language in the display log, and count all ten of them
    The serial log read "ES IS DREIVI HALB NZWOLF", which looked like a bug in
    the read-back and was not. The renderer lights positions, not letters: set
    to English it lights IT IS TWENTY PAST TWELVE, and on a German panel those
    same positions carry different letters. The face really did spell that.
    One firmware serves every panel by design, so the language now appears in
    the log line - it is the only thing that explains such a sentence.
    LANGUAGE_COUNT said 9 with languages numbered 0 to 9. That is the highest
    number, not the count. Nothing reads it yet, but a bounds check that did
    would have cut off Spanish.
    Version fallbacks in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
    [main .cpp]
2026-08-16 Remove the uptime and DCF-sync debug displays, and apply the stored mode
    Both were left from the AVR days: a DCF77 receiver drove the clock, it
    crashed often enough to want hours-since-boot on the face, and the age of
    the last radio sync was worth showing. Neither has had anything to report
    since NTP replaced DCF77. The uptime counter was the entry the display tab
    labelled "Status"; the sync-age display was not offered at all.
    Their numbers, 4 and 5, are deliberately not reused - a clock updating
    from 2.0.1 can still have 4 stored as its mode. isKnownMode() now guards
    both POST /display and the boot path, so an unknown mode falls back to
    normal display instead of matching no case and leavin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
    [main .cpp]
2026-08-17 Replace the LDR with a VEML7700 behind an interface, and add gamma
    The light sensor that was here never ran: the LDR class, its BH1750
    dependency and the block in loop() were all commented out. It goes, and
    not only because it was dead. The clock measures through a dark front
    panel, which passes a few percent of the visible light, so a lit room
    arrives as a handful of lux and the interesting range - evening and night
    - is fractions of one. The BH1750 resolves 1 lx. It was the wrong part.
    LightSensor is now an interface of one method, so a TSL2591 or an OPT3001
    is another class next to Veml7700Sensor and one line in AmbientLight. That
    matters here because the sensor sits in a different place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
    [LightSensor.cpp, LightSensor.h, main .cpp]
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2026-08-17 Hide automatic brightness when there is no sensor to drive it
    One firmware serves every build of the clock and the light sensor is an
    addition, so most have none. A switch that cannot do anything is worse
    than no switch, and it also made the old hint text - which pointed at
    src/LDR.cpp, a file that no longer exists - the only explanation on offer.
    The colour tab now asks GET /light and leaves the section out unless a
    sensor answered. It also shows the measured value, which is the whole
    point of the reading at this stage.
    The firmware clears the setting at boot when no sensor is found, rather
    than leaving it stored as on with nothing to act on it. Hiding a switch
    that is still on would other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
    [main .cpp]
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2026-08-17 Give the brightness slider back, with a second meaning
    Locking the slider while the automatic runs was wrong, and wrong in a way
    that would have blocked the next step: nudging the brightness is the only
    signal a user ever gives about whether the automatic got it right. The
    rule it followed - a control that moves and changes nothing is worse than
    one visibly not in charge - was sound; applying it by removing the control
    was not.
    With the automatic on the slider now means "at this light, I want this
    much", and POST /light {want} shifts the curve to satisfy it. The two
    calibration points keep saying how hard the clock reacts to a change in
    light; this says at what level. The endpoint is delibe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
    [LightSensor.cpp, LightSensor.h]
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2026-08-20 Keep WiFiManager alive as long as the callback it registers
    It was a local in setup(), following the library's own example and its comment
    that "once its business is done, there is no need to keep it around". True on
    the ESP8266, false here: on the ESP32, WiFi_autoReconnect() hands the Arduino
    core a callback bound to the object,
    wm_event_id = WiFi.onEvent(std::bind(&WiFiManager::WiFiEvent,this,_1,_2));
    and the core keeps it in its event list. A std::bind of a member function with
    two placeholders does not fit std::function's small buffer, so the target is on
    the heap, and the destructor at the end of setup() frees it while WiFi events
    keep arriving.
    Found while hunting the boot loop, w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
    [main .cpp]
2026-08-20 Turn the transmit power down to 13 dBm
    The part comes up at its maximum, 19.5 dBm, and a transmit burst at that level
    pulls 350-500 mA for a moment. A board fed through a USB cable, with 114
    WS2812B on the same 5 V, does not always have that to give: the 3.3 V rail dips,
    the radio drops out mid-burst, and what you see is an access point that appears
    for a second and is gone again - a symptom that looks like anything except a
    supply problem. A mismatched antenna does the same thing by a different route,
    through reflected power, and from the outside the two are hard to tell apart.
    13 dBm is 6 dB down, a quarter of the power.
    It has to be set per interface and after that interface has started,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
    [main .cpp]
2026-08-20 Add the TSL2591 beside the VEML7700, and pick whichever answers
    Second implementation of the LightSensor interface, which is what the interface
    was for. The TSL2591 resolves to roughly 188 uLx against the VEML7700's 3.6 mLx
    and the BH1750's 0.11 lx, and that only matters at the dark end - which is the
    whole point. Behind a front panel an evening living room arrives as a fraction
    of a lux, and a sensor reporting a flat 0 there cannot tell dusk from night, so
    the automatic sits at its floor all evening.
    The Adafruit library has no auto-ranging, which turns out to be the better deal.
    Walking the whole range in one call is what makes the VEML7700 block for over a
    second and the reason the sampl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
    [LightSensor.cpp, LightSensor.h]
2026-08-20 Bring the board and the enclosure into the repository
    The 250 mm build: KiCad project for the 11x10 matrix with its four corner LEDs,
    the decoupling capacitors and the alternating +5V/GND pours, plus body.scad for
    the enclosure.
    Two scripts travel with it, both meant for KiCad's own scripting console rather
    than for the IPC bridge - bulk work through the bridge crashed the editor twice.
    place_matrix.py computes the lattice instead of storing it, so a change of pitch
    is a change of one number, and place_matrix and power_zones share the same
    constants. power_zones.py carries a long note about pcbnew's Remove(): it hands
    the C++ object to Python without a destructor, and once the proxy is coll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
    [Qlock250mm.kicad_pcb, Qlock250mm.kicad_sch, body.scad]
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2026-08-20 Put the update and debug tabs behind a password
    Both let whoever is on the network do something they should not: flash the
    clock, and read everything it has said about itself. That was defensible while
    neither existed as a web page. The log arriving in a browser changed it.
    One flag in NVS says whether the clock is unlocked. While it is 0, /ota/* and
    /log answer 403 {"error":"expertLocked"} and the web UI does not offer the
    tabs at all. Expert::guard() is the one line at the top of every covered
    handler, and the header names all six so the list cannot quietly grow.
    A mode, not a login. Setting the flag needs the password; clearing it does
    not, since someone locking the clock out of spite h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
    [main .cpp]
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2026-08-20 Let OpenSCAD cut the panel the firmware renders
    body.scad kept its own copy of the letter grid. The firmware checks its
    panels at every boot - every word against the letters underneath it - and
    a hand-copied array in a SCAD file gets none of that. The two still
    agreed, which is luck rather than a system; the failure mode is a milled
    mask with a letter in the wrong place, found after the print.
    scripts/panels.py reads the rows out of the language files and writes
    panels.scad, committed like zones.json and the icons: OpenSCAD cannot run
    Python, and a print should not need a toolchain that happens to be
    installed. Seven panels for ten languages, since the German dialects
    share one.
    Rendered b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
    [body.scad, panels.scad]
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2026-08-22 Let a letter and its apostrophe share one cell
    English wants O'CLOCK and Italian L'UNA, and on the panel the letter and
    its apostrophe are one milled opening behind one LED. Both were faked
    with a lookalike single character - Ò for O', Ľ for L' - which read
    wrongly on the wall and spelled wrongly in the log.
    A cell is now a character plus a U+2032 PRIME if one follows, which needs
    no separator in the row string: "TENSEO′CLOCK" is twelve characters and
    eleven cells. Languages::cells() and appendCell() are the only two places
    that know the rule; panels.py and panel.js repeat it for OpenSCAD and for
    the browser, and the SCAD array gets "O′" as one element, which is what
    the mask has to b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
    [panels.scad]
2026-08-22 Take the apostrophe people actually type
    The cell rule accepted only U+2032 PRIME. The first panel written after
    it was built used a plain ASCII apostrophe, which is what is on the
    keyboard, and got "row 9: 12 cells, expected 11" for its trouble.
    So the mark is now ' , with U+2019 and U+2032 taken as the same thing -
    not to be accommodating, but so that a panel pasted in from somewhere
    else fails on the word it disagrees with rather than on a cell count
    nobody can act on. Nothing is normalised: whatever was written is what
    the panel, the log, /panel and the SCAD array all spell.
    Italian moves to the plain one with it. English is mid-edit in the
    working tree and follows there.
    Co-Authored-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
    [panels.scad]
2026-08-22 Take the panel work in, and check what a comment cannot promise
    English, Spanish and Dutch, plus the two checks that found the one thing
    wrong with them.
    The panels themselves were consistent - every word spelled by the letters
    underneath it, every row eleven cells. What was not was the drawing in
    the header comment of Language_NL, which showed HALFSPMOVER against a row
    reading HALFSMPOVER. PM is a thing and MP is not, and the file has an AM
    and a PM elsewhere, so the drawing was right and the row had a
    transposition. Fixed to HALFSPMOVER.
    That drawing is a comment, so nothing has ever forced it to be true, and
    it had quietly disagreed with its rows three times now. panels.py checks
    it. It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
    [panels.scad]
2026-08-22 Give Italian back its Ľ
    L'UNA becomes Ľ (U+013D, L with caron) again: one character that carries
    its own mark, cut as one glyph, needing no rule at all.
    The apostrophe rule stays for English, which has no such character for
    O'. Both files now say why they do it their way, because the obvious
    reading of two panels solving one problem differently is that somebody
    forgot to finish, and the next person would make them match.
    What made the old Ľ wrong was never the character - it was the word
    underneath still saying LUNA, so the panel and its own word disagreed and
    selfCheck said so at every boot. That half is fixed and stays fixed.
    [panels.scad]
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2026-08-22 Give the two stores a tab of their own, and NVS a tree
    The file explorer moves out of the debug tab into a seventh tab with
    two panels: LittleFS, and NVS drawn as if it were a filesystem -
    namespaces as folders, keys as files, .json or .bin depending on what
    the value turns out to be.
    It is not a filesystem, and the four places the pretence stops are
    written down rather than left to be found: no third level, nothing to
    upload, the extension is a reading of the content, and sizes are
    entries because that is what nvs_get_stats counts. One value is not
    readable at all - the expert password hash and its salt are the only
    secret here whose leak outlives the unlock that leaked it.
    One component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
    [main .cpp]
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2026-08-22 Anchor the brightness line on the newest point, and show what is lit
    Asking for 55 % and waiting out the ten seconds gave back 47 %: least
    squares puts the line through the centroid, not through the point just
    made. Worse, nudging again at the same light replaced the same point
    and produced the same 47 %, so the correction could never converge.
    The slope is the room and stays least squares over every point. The
    level is the instruction and now comes from the newest point alone -
    the line is moved to pass exactly through it. The store is chronological
    instead of a ring with a cursor, so "newest" means something and the
    saved order really is the order things happened.
    `applied` in /light and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
    [main .cpp]
2026-08-22 A lab interface, and it found the sensor in four minutes
    /lab hands a script every pixel and the light sensor directly: raw
    colours with no gamma or brightness scaling, synchronous unsmoothed
    readings with the sensitivity rung pinnable, and a whole measurement
    series in one request so network jitter stays out of the numbers.
    scripts/lab.py is the client and the experiments live there, so a new
    idea costs a script rather than a flash cycle.
    It is behind expert mode and owns the strip through a display mode that
    cannot be stored, cannot be picked, and ends with a restart.
    What it found on the first clock:
    the wiring in three files was wrong and the code was right - the strip
    starts at t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
    [LightSensor.cpp, LightSensor.h, main .cpp]
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
